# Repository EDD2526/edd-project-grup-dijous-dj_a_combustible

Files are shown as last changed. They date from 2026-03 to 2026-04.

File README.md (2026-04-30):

View this project on [CADLAB.io](https://cadlab.io/project/30195). 

# Projecte DJ_A_combustible

>**Autors: Edgar Castro i Pere Ribas
>**Versió: Final

----------

## Objectiu

Monitorització en temps real el nivell de combustible i les seves condicions (pressió/temperatura).

Control de la bomba de combustible i el tancament de seguretat de forma automàtica.

Bona connexió amb el vehicle per a que altres unitats de control tinguin accès a la informació.

## Diagrama de blocs
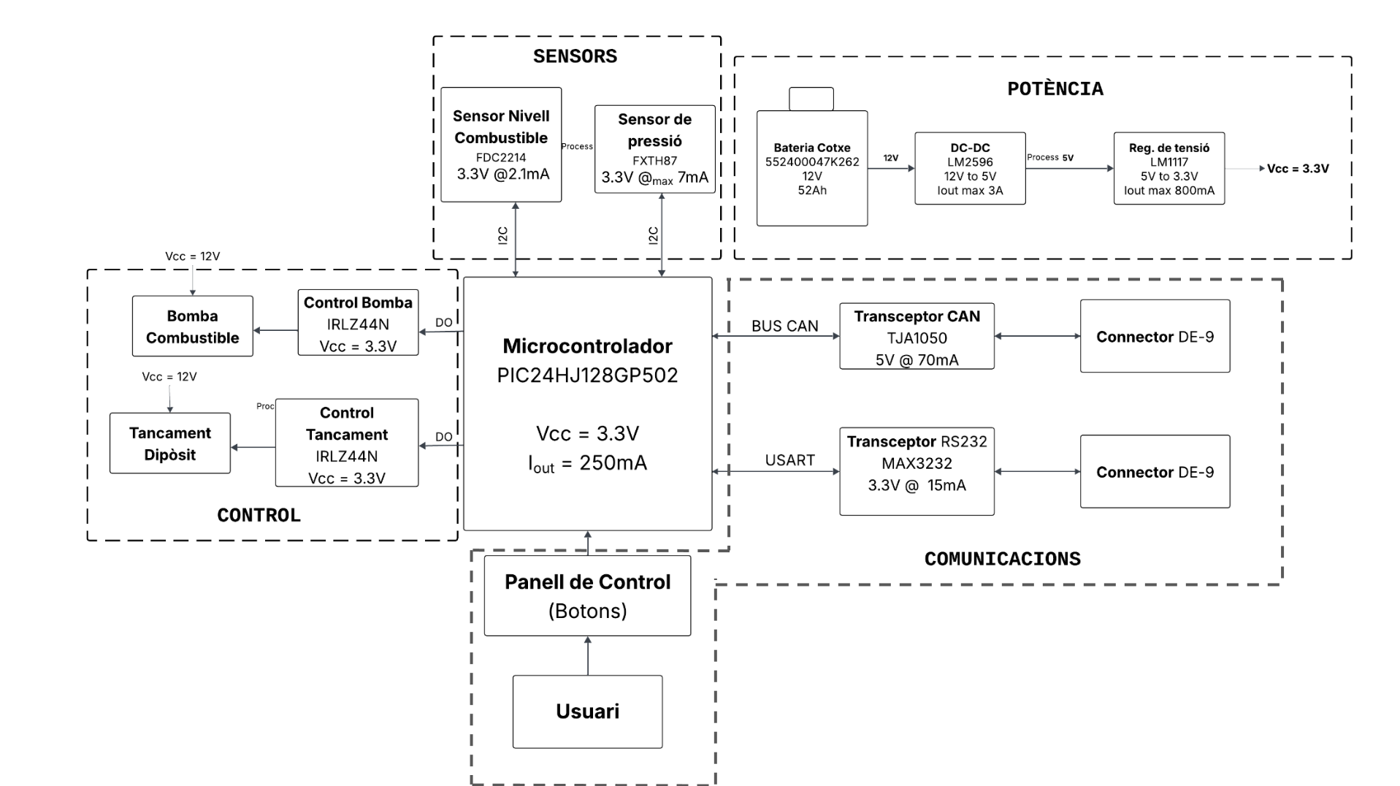
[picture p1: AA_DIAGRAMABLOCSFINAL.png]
Diagrama_de_blocs


### Descripció/funcionalitat de cada bloc

  **Etapa 1, Alimentació**
  Etapa dedicada a protegir i alimentar tots els altres blocs del projecte.
  Primer els 12V seran protegits amb díodes, i aquests serviran per a la bomba del combustible i el tancament del dipòsit.
  A partir d'aqui baixarem a 3.3V que ens servirà per alimentar el nostre Micro.

  **Etapa 2, Control**
  Etapa destinada a ser el cervell del projecte.
  Trobem el micro, encarregat de rebre informació a través dels sensors, del CAN i del MAX3232, i de donar ordres ja siguin programades o especificades per l'usuari mitjançant els botons.
  Disposem també d'un conncetor per a la possible programació, de dos DE9 pels transceptors i d'un clock.
  També tenim la botonera per a controlar el tancament del dipòsit i la bomba de combustible.

  **Etapa 3, Potència**
 Etapa destinada a controlar mitjançant dos MOSFETs els motors de la Bomba de Combustible i el Tancament del Dipòsit.
 A més per a major protecció s'han afegit dos relés i dos díodes pels sobrepics de tensió.

  **Etapa 4, Sensors**
 Etapa on hi han els sensors de nivell de combustible FDC2214 i el sensor de pressió dels pneumàtics FXTH87 amb les connexions adequades.

-----------

## Requisits / Especificacions

  * Alimentació; 12V, regulada 5V i 3.3V
  * Microcontrolador PIC24HJ128GP502
  * Mòdul RF Receptor
  * Sensor de Combustible: FDC2214
    
  ### Regles de disseny 
  * Marge mínim: 0.2mm
  * Amplada mínima de la pista: 0.1mm
  * Amplada mínima de conenxionat: 0.2mm
  * Marge de cobre a forat: 0.25mm
  * Diàmetre mínim de uVia: 0.25mm
  * Orifici mínim de uVia: 0.15mm
  * Modificacions de la serigrafia

**Classes de nodes i amplada**
  * GND → 0.2mm
  * GND_PWR → 0.5mm
  * Alimentació → 0.5mm
  * 5V → 0.3mm
  * 3.3V → 0.2mm
  * Default → 0.25mm

-----------

## Components

| Descripció | Ref | Package | Datasheet | Proveïdor | Preu Unitari | Unitats |
| --- | --- | --- | --- | --- | --- | --- |
| **Microcontrolador PIC24 (16-bit)** | U20 | SOIC-28W | [Datasheet](http://ww1.microchip.com/downloads/en/DeviceDoc/70293G.pdf) | [Mouser](https://www.mouser.es/ProductDetail/Microchip-Technology/PIC24HJ128GP502-I-SO?qs=Fllw7YelV39GXmNd3htPpg%3D%3D) | 5,86€ | 1x |
| **Mòdul RF Receptor** | XY-MK-5V | - | [Datasheet](https://www.berrybase.ch/en/product-datasheet/019234a3d36272808ea5c21625235fe6/create) | [Digikey](https://www.digikey.es) | 4,95€ | 1x |
| **Sensor Capacitiu (Combustible)** | U6 | QFN-16 | [Datasheet](https://www.ti.com/lit/ds/symlink/fdc2214.pdf) | [Mouser](https://www.mouser.es/ProductDetail/Texas-Instruments/FDC2214RGHR?qs=GJ%2F2ZGcr5uPBUC9HQa0OnA%3D%3D) | 5,38€ | 1x |
| **Relé SPST-NO (6A)** | K1, K2 | Vertical THT | [Datasheet](https://www.fujitsu.com/sg/imagesgig5/ftr-ly.pdf) | [Digikey](https://www.digikey.es) | 1,49€ | 2x |
| **MOSFET N-Channel** | Q1, Q2 | TO-220F-3 | [Datasheet](http://www.irf.com/product-info/datasheets/data/irliz44n.pdf) | [Digikey](https://www.digikey.es) | 1,29€ | 2x |
| **Regulador Step-Down 12V** | U1 | TO-263-5 | [Datasheet](http://www.ti.com/lit/ds/symlink/lm2596.pdf) | [Digikey](https://www.digikey.es) | 6,18€ | 1x |
| **Regulador LDO 3.3V** | U2 | TO-252-3 | [Datasheet](http://www.ti.com/lit/ds/symlink/lm1117.pdf) | [Digikey](https://www.digikey.es) | 1,15€ | 1x |
| **Transceptor CAN** | U3 | SOIC-8 | [Datasheet](http://www.ti.com/lit/ds/symlink/sn65hvd230.pdf) | [Digikey](https://www.digikey.es) | 1,94€ | 1x |
| **Driver RS232** | U4 | SOIC-16 | [Datasheet](https://datasheets.maximintegrated.com/en/ds/MAX3222-MAX3241.pdf) | [Digikey](https://www.digikey.es) | 1,91€ | 1x |
| **Díode Rectificador (Flyback)** | D_p_bomba1, 2 | DO-41 THT | [Datasheet](http://www.vishay.com/docs/88503/1n4001.pdf) | [Digikey](https://www.digikey.es) | 0,18€ | 2x |
| **Díode Schottky (DCDC)** | D_schottky1 | D_SMA | [Datasheet](https://ww1.microchip.com/downloads/aemdocuments/documents/HRDS/ProductDocuments/DataSheets/1n5823-25.pdf) | [Digikey](https://www.digikey.es) | 0,88€ | 1x |
| **Díode Zener 14V** | D_Zener1 | D_SOD-123 | [Datasheet](https://www.mouser.es/datasheet/3/225/1/SMBJ5338B-SMBJ5388B(SMB).pdf) | [Digikey](https://www.digikey.es) | 0,17€ | 1x |
| **Díode Protecció (MBR0520)** | D_Proteccio1 | D_SOD-123 | [Datasheet](http://www.mccsemi.com/up_pdf/MBR0520~MBR0580(SOD123).pdf) | [Digikey](https://www.digikey.es) | 0,12€ | 1x |
| **Cristall de Quars** | Y1 | SMD 5032-2 | [Datasheet](https://www.mouser.es/datasheet/3/294/1/ecx_53r.pdf) | [Digikey](https://www.digikey.es) | 0,59€ | 1x |
| **Pulsadors (Slide/DIP)** | SW1, SW2, SW3 | SMD DIP | [Datasheet](https://www.mouser.es/datasheet/3/6118/1/slw-166261-4a-ra-n-d.pdf) | [Digikey](https://www.digikey.es) | 0,95€ | 3x |
| **Connector DB9 (RS232)** | J1, J2 | DSUB-9 | [Datasheet](https://www.mouser.es/datasheet/3/59/2/CN_DSUB9SKT00.pdf) | [Mouser](https://www.mouser.es) | 23,48€ | 2x |
| **Connectors Bomba/Tancament** | J4, B1, T1 | Pin 1x02 | [Datasheet](https://www.we-online.com/components/products/datasheet/61300211121.pdf) | [Digikey](https://www.digikey.es) | 0,11€ | 3x |
| **Connector Prog. PIC (ICSP)** | J3 | Pin 1x05 | [Datasheet](https://www.we-online.com/components/products/datasheet/61300211121.pdf) | [Digikey](https://www.digikey.es) | 0,22€ | 1x |
| **Connector Prog. Sensor (BKGD)** | J5 | Pin 1x04 | [Datasheet](https://www.we-online.com/components/products/datasheet/61300211121.pdf) | [Digikey](https://www.digikey.es) | 0,16€ | 1x |
| **Inductor 33uH (DCDC)** | L_DCDC1 | SRP7028A | [Datasheet](https://www.bourns.com/docs/product-datasheets/srp7028a.pdf) | [Digikey](https://www.digikey.es) | 0,94€ | 1x |
| **Inductor 18uH (Filtre)** | L1 | L_0805 | [Datasheet](https://product.tdk.com/system/files/dam/doc/product/inductor/inductor/smd/catalog/inductor_commercial_decoupling_mlz2012_en.pdf) | [Digikey](https://www.digikey.es) | 0,11€ | 1x |
| **Ferrite Bead** | FB1 | L_1812 | [Datasheet](https://www.we-online.com/components/products/datasheet/7427922.pdf) | [Digikey](https://www.digikey.es) | 0,25€ | 1x |
| **Condensador 680uF** | Cin_DCDC1 | Radial D10mm | [Datasheet](https://industrial.panasonic.com/cdbs/www-data/pdf/RDF0000/ABA0000C1259.pdf) | [Digikey](https://www.digikey.es) | 0,93€ | 1x |
| **Condensador 220uF** | Cout_DCDC1 | Radial D10mm | [Datasheet](https://industrial.panasonic.com/cdbs/www-data/pdf/RDF0000/ABA0000C1259.pdf) | [Digikey](https://www.digikey.es) | 0,61€ | 1x |
| **Condensador 100uF** | Cout_reg1 | Radial D5mm | [Datasheet](https://industrial.panasonic.com/cdbs/www-data/pdf/RDF0000/ABA0000C1259.pdf) | [Digikey](https://www.digikey.es) | 0,33€ | 1x |
| **Condensadors 10uF** | C7, Cin_reg1 | C_0805 | [Datasheet](https://datasheets.kyocera-avx.com/AutoMLCC.pdf) | [Digikey](https://www.digikey.es) | 0,14€ | 2x |
| **Condensadors 100nF** | C1-C9, C32-33 | C_0805 | [Datasheet](https://datasheets.kyocera-avx.com/AutoMLCC.pdf) | [Digikey](https://www.digikey.es) | 0,08€ | 10x |
| **Condensadors 22p** | C10, C11 | C_0805 | [Datasheet](https://datasheets.kyocera-avx.com/AutoMLCC.pdf) | [Digikey](https://www.digikey.es) | 0,08€ | 2x |
| **Condensador 33p** | C20 | C_0805 | [Datasheet](https://datasheets.kyocera-avx.com/AutoMLCC.pdf) | [Digikey](https://www.digikey.es) | 1,04€ | 1x |
| **Resistència 10k** | R1-R21 (varies) | R_0805 | [Datasheet](https://www.vishay.com/docs/20035/dcrcwe3.pdf) | [Digikey](https://www.digikey.es) | 0,08€ | 4x |
| **Resistència 4.7k** | R3, R4 | R_0805 | [Datasheet](https://www.vishay.com/docs/20035/dcrcwe3.pdf) | [Digikey](https://www.digikey.es) | 0,08€ | 2x |
| **Resistència 220** | R22, R23 | R_0805 | [Datasheet](https://www.vishay.com/docs/20035/dcrcwe3.pdf) | [Digikey](https://www.digikey.es) | 0,16€ | 2x |
| **Resistència 120 (CAN)** | R_CAN1 | R_0805 | [Datasheet](https://www.vishay.com/docs/20035/dcrcwe3.pdf) | [Digikey](https://www.digikey.es) | 0,08€ | 1x |

-----------

## Software

### Eines:

  * KiCad 9.0 o superior
  * LTspice
  * Lucid

### Funcionalitats:

  * El tancament i obertura del tanc de combustible
  * L'activació de la bomba que subministra el combustible al motor del vehicle
  * Captar informació sobre el nivell de combustible a través d'un sensor digital per a comunicar amb l'usuari
  * Mesurar activament la pressió dels pneumàtics del cotxe. En aquest cas, amb un receptor RF es reben les dades captades per un sensor de pressió (el sensor no forma part del projecte ja que físicament no té sentit que sigui a la pcb, sinó aprop del pneumàtic).
  * Comunicar tota aquesta informació a l'usuari del vehicle i a tot el vehcile en sí a través de diferents mètodes d'enviament de dades (UART i CAN).  

-----------

## Historial de canvis
### 15/03/2026
Hem millorat el diagrama de blocs, tant l'etapa 1 com la 3.
A més he fet que les fletxes siguin més gruixudes per tal que es vegin millor.
Al KiCad he obert l'esquemàtic i he **creat els subesquemàtics**, en els quals només he posat els noms de les etapes 1 i 3.
I he fet una **carpeta** per anar posant les millores dels **diagràmes de **blocs**.
Realment del diagrama de blocs només quedaria posar el **nom i especificacions generals dels components que falten**,  acabar de modificar una mical del **disseny del diagrama** i ja estaria acabat.

### 19/03/2026
Hem millorat el diagrama de blocs, amb les correccions dels professors.
També hem començat la part esquemàtica de les diferents etapes a KiCad. En general, s'ha avançat gran part, quedarien connectar pocs pins i definir-los correctament, entendre bé el funcionament i les correccions del professor. 
A més, també haurem de millorar l'organització dels subesquemàtics creats a la carpeta compartida per tal d'aquesta manera tenir una millor visualització i entendre les etapes millor. 
Properament haurem de assignar valors als diferents components i optimitzar algun circuit

### 22/03/2026
S'ha *finalitzat definitivament el diagram de blocs*.
A l'etapa de control s'ha **afegit** un **relé** per a major **protecció** per al microcontrolador degut a les grans càrregues i potències que pot comportar el funcionament de la bomba i el tancament.
S'ha **afegit** el símbol del sensor de combustible **FDC2214**, falta **crear** el símbol del sensor de pressió **FXTH87**

### 24/03/2026
A dia d'avui, en principi no queda pràcticament res (de la part de l'esquemàtic). S'ha avançat gran part del que ens vam proposar en la darrera sessió de pràctiques, com la forma dels pins, afegir els pins que faltaven, els valors dels components, etc., juntament amb les correccions del professor. A banda d'això, també s'ha afegit una part de programació ICSP per a que l'usuari pugui controlar al seu gust mitjançant un connector extern del propi usuari al microcontrolador. 
A la tarda d'avui, només queda (de moment) crear el símbol del sensor de pressió i connectar els pins corresponents.

### 25/03/2026
**Esquemàtic acabat** abans de l'última sessió (a falta de les correccions que es faràn demà a classe).
S'ha continuat fent el Readme on s'han anat emplenant diferents apartats.
A banda d'això s'hauria d'**anar triant les petjades**, sobretot pels símbols que hem creat nosaltres o els que no estem acostumats a treballar, ja que per components passius o que ja hem tocat, les petjades suposem que seran les mateixes i que no les haurem de crear ni afegir al KiCad

### 29/03/2026
La **majoria de petjades s'han afegit**. Tots els components que no son resistències o capacitats ja tenen **petjada**.
Falta **mirar** els **pins FXTH87** ja que els pins possiblement estiguin **mal posats** i el **footprint no coincideixi** i falta repassar el propi datasheet per saber quin footprint triar.
*Altres footprints que falten:*
Cristall
Connectors 1x2 i 1x5
Díodes
Bobines
Resistències i Capacitats
També s'hauràn d'afegir les petjades i datasheets al README

### 04/04/2026
**Totes les petjades afegides**
Sensor de pressió acabat
Falta posar les petjades al readme
**Esquemàtic acabat (en teoria)**

### 08/04/2026
**Placement V1**, falta posar tots els components passius, però com és un placement i a sobre quasi al 100% s'haurà de canviar una mica, posar aquests components és perdre el temps.
Hem començat també a posar els proveïdors i els preus a la llista del Readme i s'ha actualitzat la foto per a que es vegi

### 15/04/2026
Començament del ruteig

### 16/04/2026
Modificació correccions per part del professorat. Afegim captures de diferents versions de del routing (ERC amb 0 errors). Faltaria veure si hi ha alguna cosa a corregir i passar a la part final del projecte.

### 29/04/2026
Últims retocs al esquemàtic i al layout. S'ha fet la presentació, final, s'han afegit els gerbers, BOM, fotos 3D del layout final i fotos de l'esquemàtic.
Pressupost fet i afegida la carpeta del pressupost al projecte.
**Falta acabar el readme, la taula de components**

### 30/04/2026
Tot preparat (des d'ahir). Presentació realitzada amb el procés d'aquest projecte. Nervis d'últim dia, però està controlat!

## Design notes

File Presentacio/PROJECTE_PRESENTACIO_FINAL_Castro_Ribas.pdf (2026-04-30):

# Projecte Combustible

## Edgar Castro i Pere Ribas

PRESENTACIÓ FINAL
30/04/2026

## Objectius

→ Monitorització en temps real el nivell de combustible i les seves condicions (pressió/temperatura).

→ Control de la bomba de combustible i el tancament de seguretat de forma automàtica.

→ Bona connexió amb el vehicle per a que altres unitats de control tinguin accès a la informació.

## Requeriments i especificacions

- Alimentació; 12V, regulada 5V i 3.3V
- Microcontrolador PIC24HJ128GP502
- Mòdul RF Receptor
- Sensor de Combustible: FDC2214

## Requeriments i especificacions

- Regles de disseny

→ Marge mínim: 0.2mm

→ Amplada mínima de la pista: 0.1mm

→ Amplada mínima de conenxionat: 0.2mm

→ Marge de cobre a forat: 0.25mm

→ Diàmetre mínim de uVia: 0.25mm

→ Orifici mínim de uVia: 0.15mm

→ Modificacions de la serigrafia

## Requeriments i especificacions

- Classes de nodes i amplada

GND → 0.2mm

GND_PWR → 0.5mm

Alimentació → 0.5mm

5V → 0.3mm

3.3V → 0.2mm

Default → 0.25mm

## Diagrama de blocs final

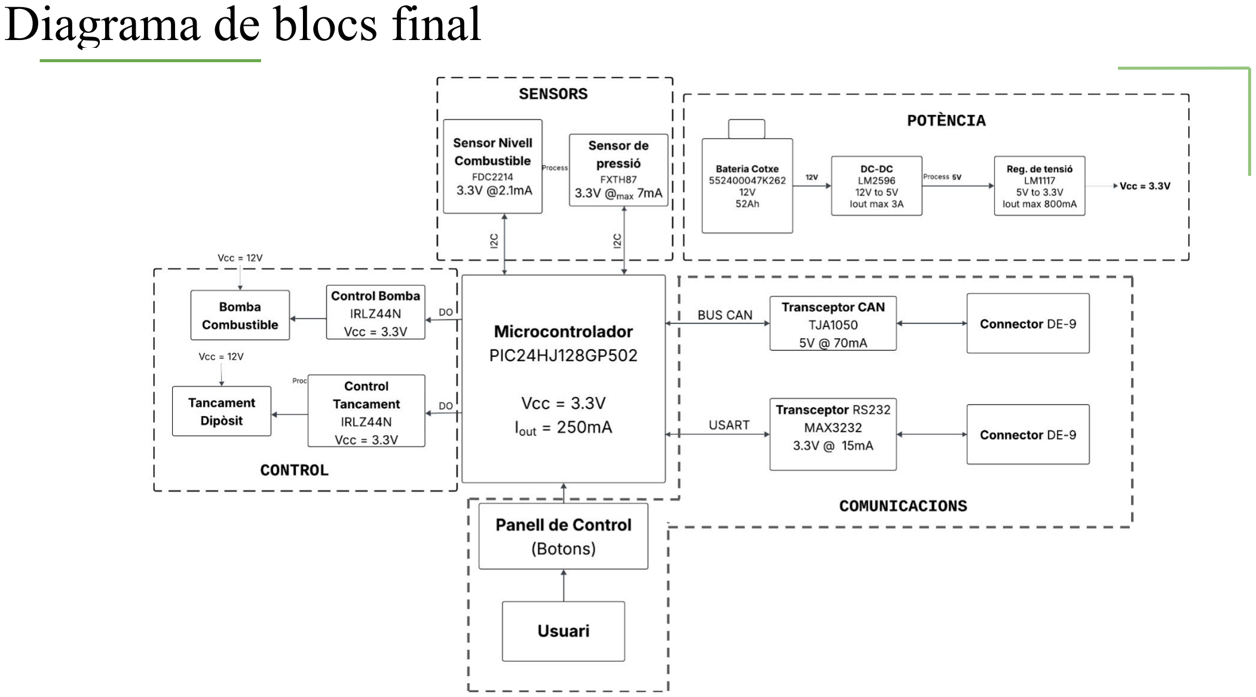
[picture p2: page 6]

## Diferents funcionalitats de cada bloc

Bloc 1 → Alimentació

- Protecció i alimentació de la resta de blocs. Començant en 12 [V] i passant a 3V3.

Bloc 2 → Control

- Cervell del projecte. Encarregat de rebre i donar ordres (programades o per part de l’usuari) mitjançant els seus connectors DE9.

## Diferents funcionalitats de cada bloc

Bloc 3 → Potència

- S’encarrega, mitjançant MOSFETs del control de la bomba del combustible i del control del tancament, amb dos relés i dos díodes per una major protecció.

Bloc 4 → Sensors

- Una última etapa amb funció de sensors, per controlar la pressió dels pneumàtics i el nivell de combustible.

## Diferents decisions que hem hagut de prendre

Creació de símbols i alternatives (gràcies a datasheets).

Col·locació dels components a l’hora de realitzar el layout.

Sensor de pressió o receptor RF

## Esquemàtic

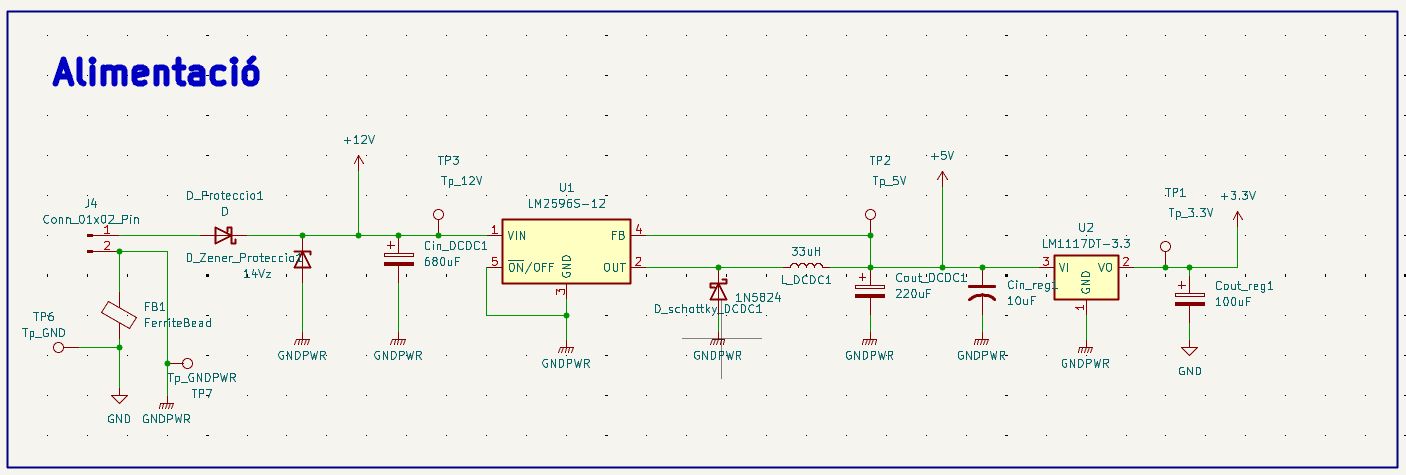
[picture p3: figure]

## Esquemàtic

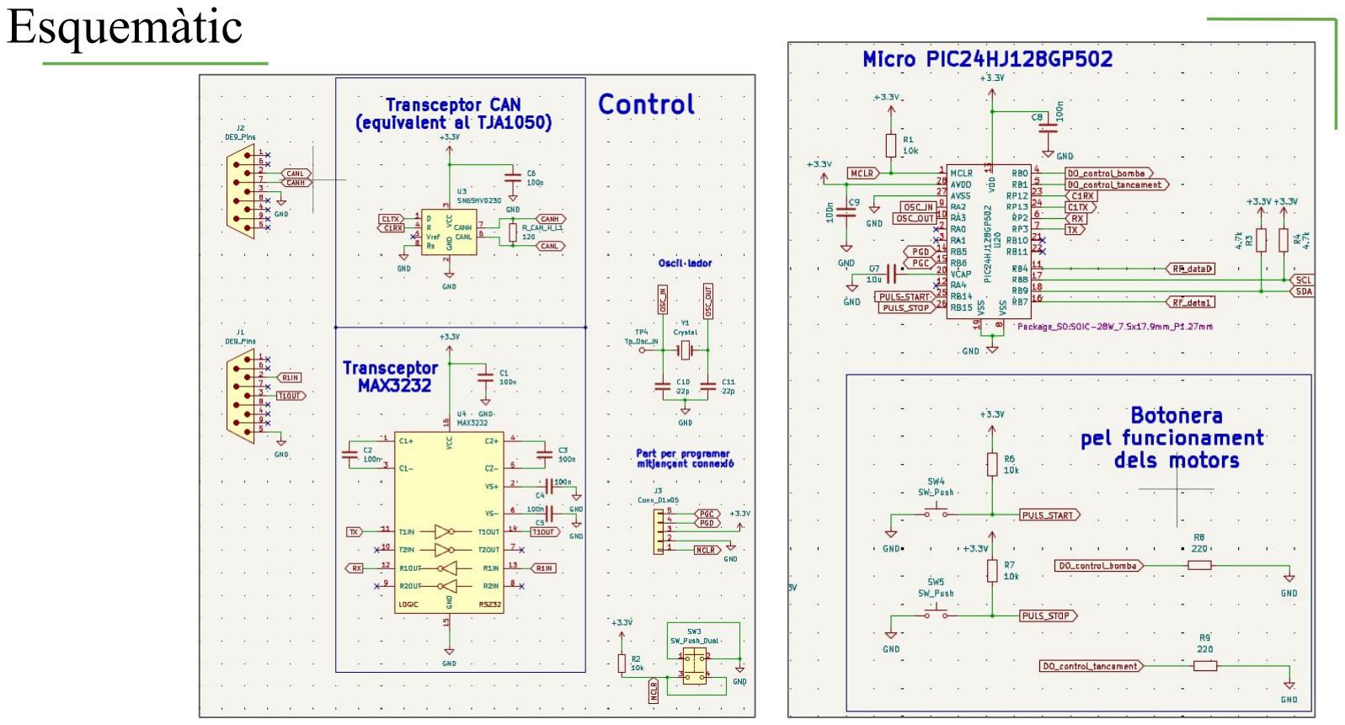
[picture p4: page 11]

## Esquemàtic

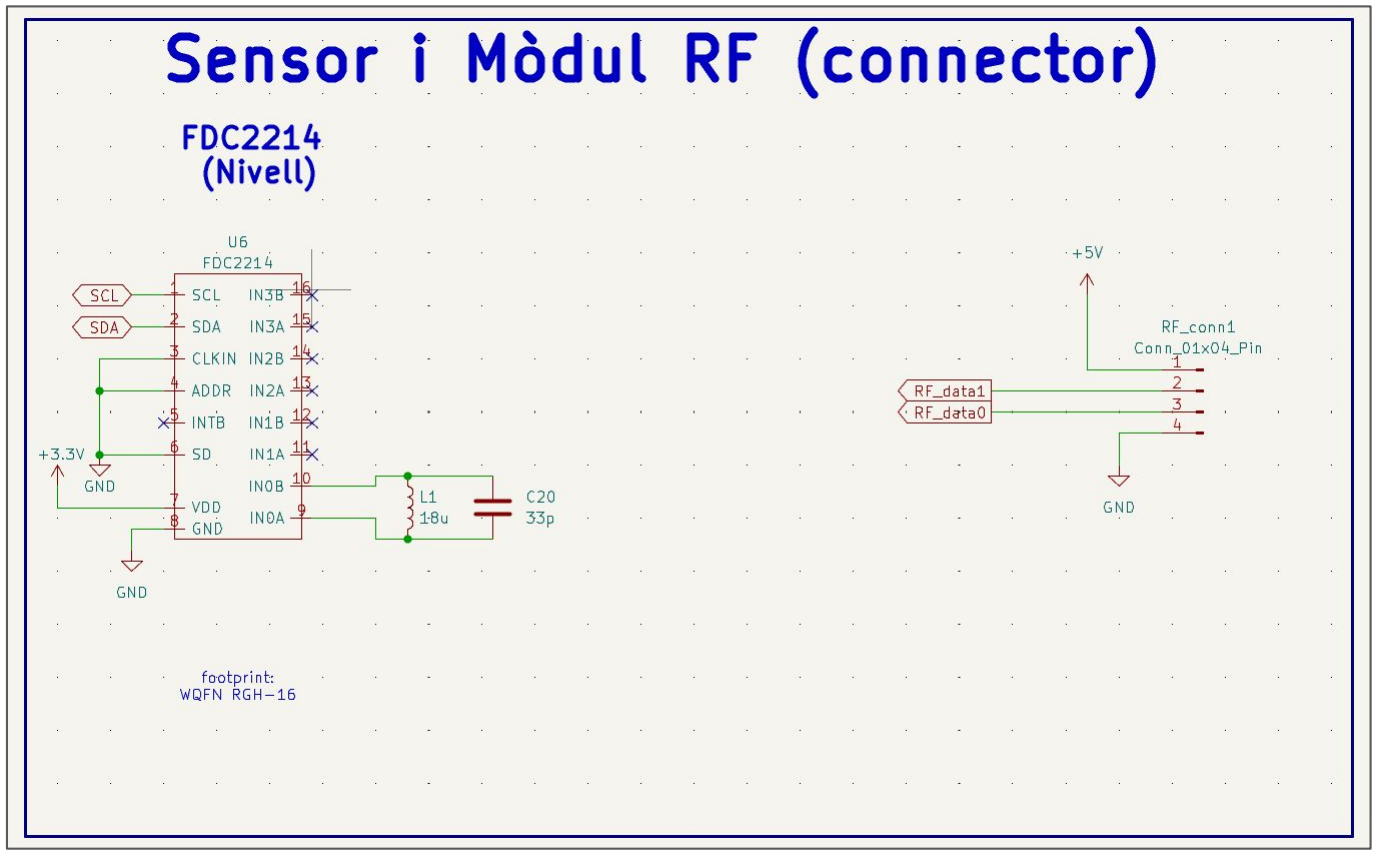
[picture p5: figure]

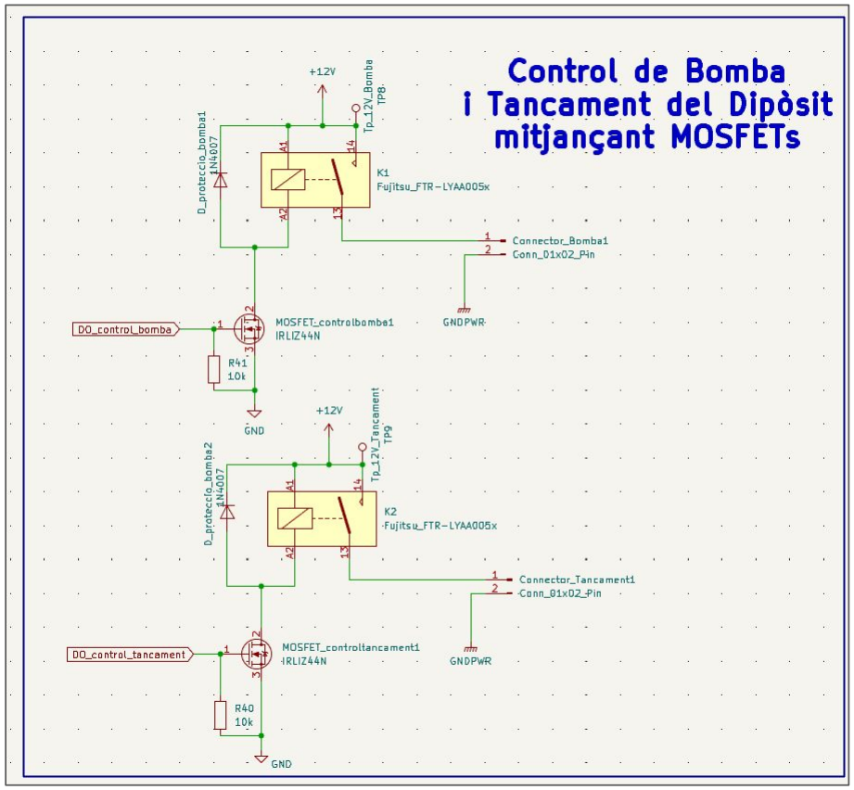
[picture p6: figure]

## Esquemàtic

## Layout

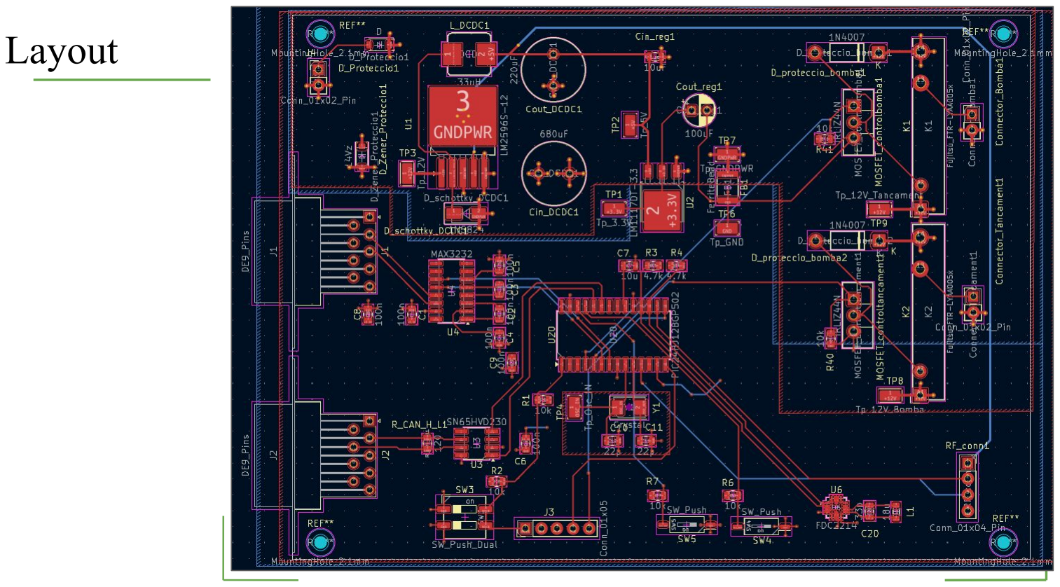
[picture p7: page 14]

## Layout 3D

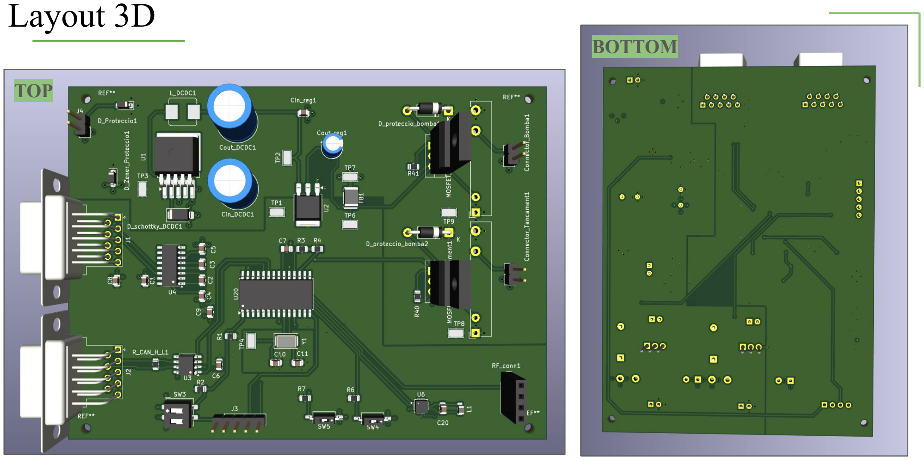
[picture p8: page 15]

TOP

BOTTOM

## Anàlisi de costos

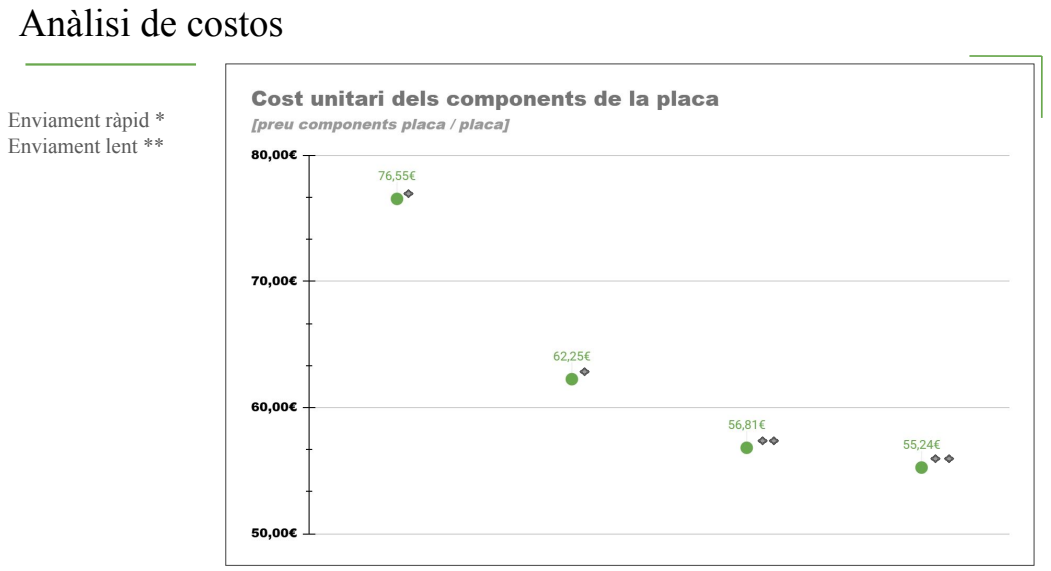
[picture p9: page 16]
Enviament ràpid * Enviament lent **

## Anàlisi de costos

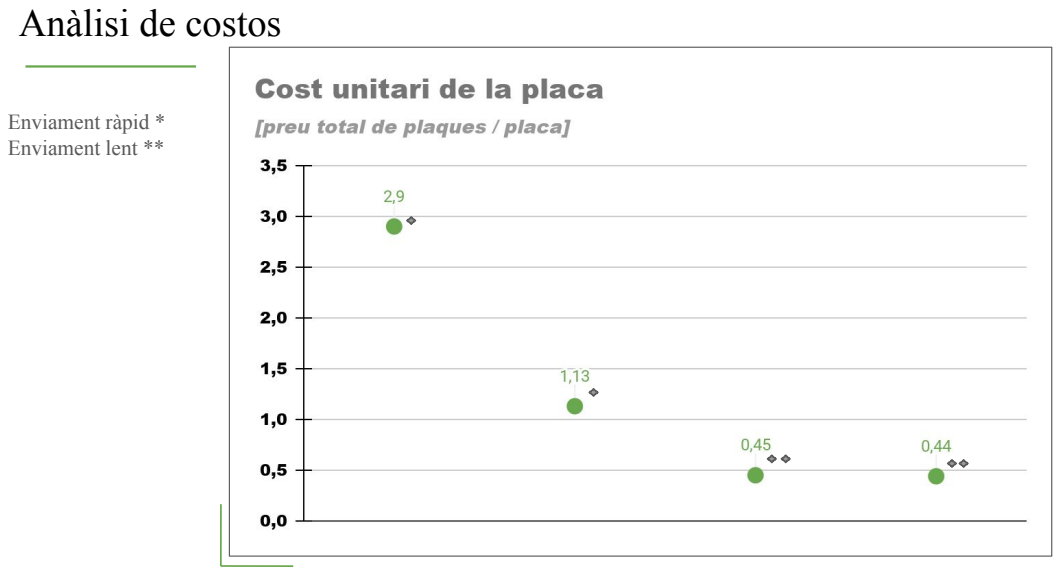
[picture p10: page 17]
Enviament ràpid * Enviament lent **

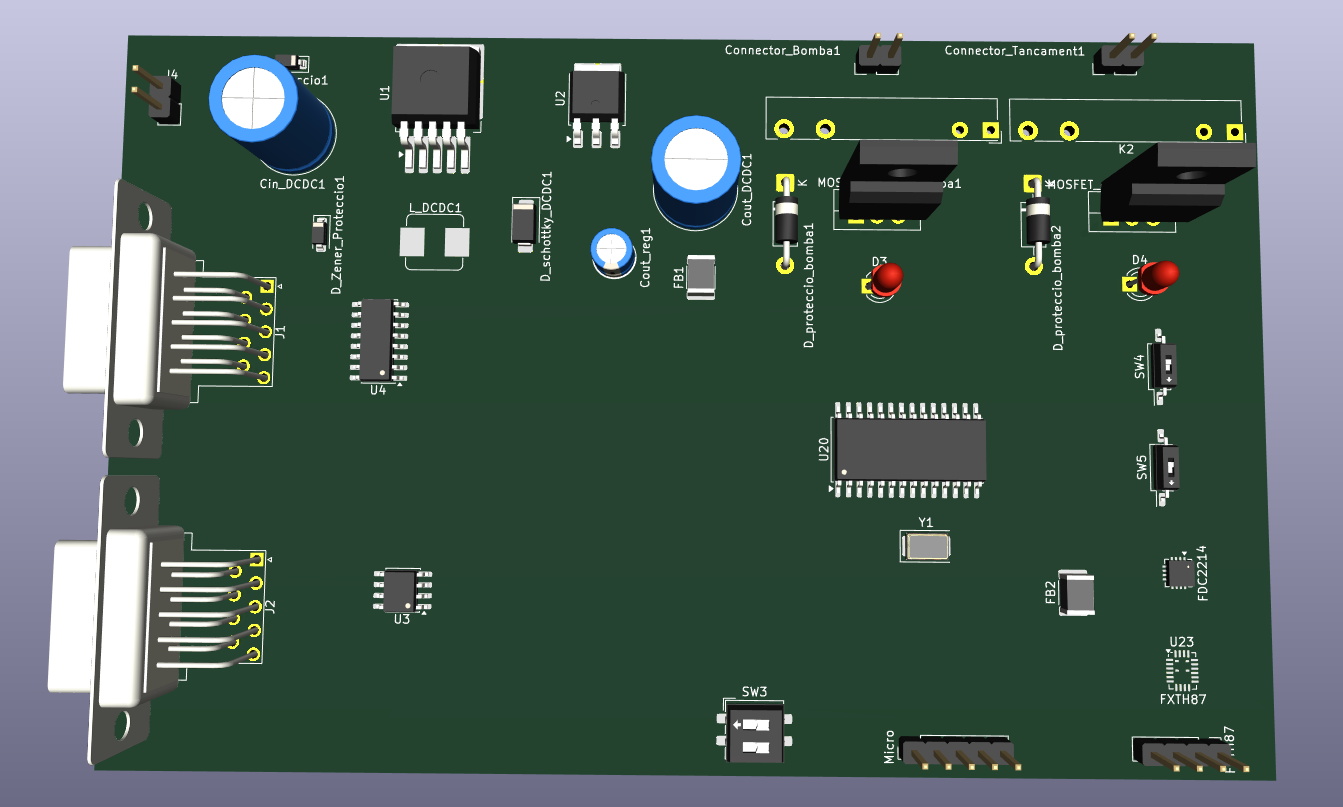
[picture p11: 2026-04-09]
Layout/layout3D_v1.png

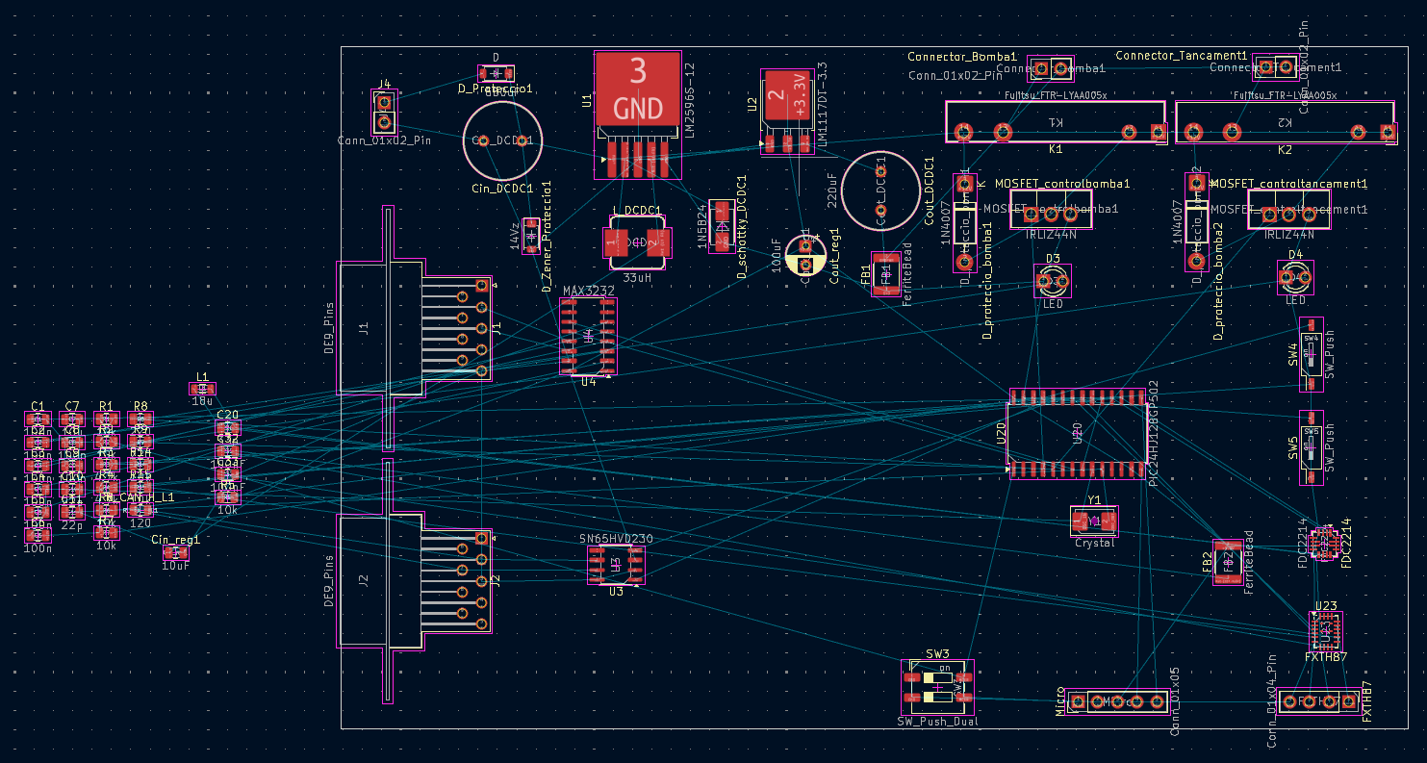
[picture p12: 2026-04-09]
Layout/layout_v1.png

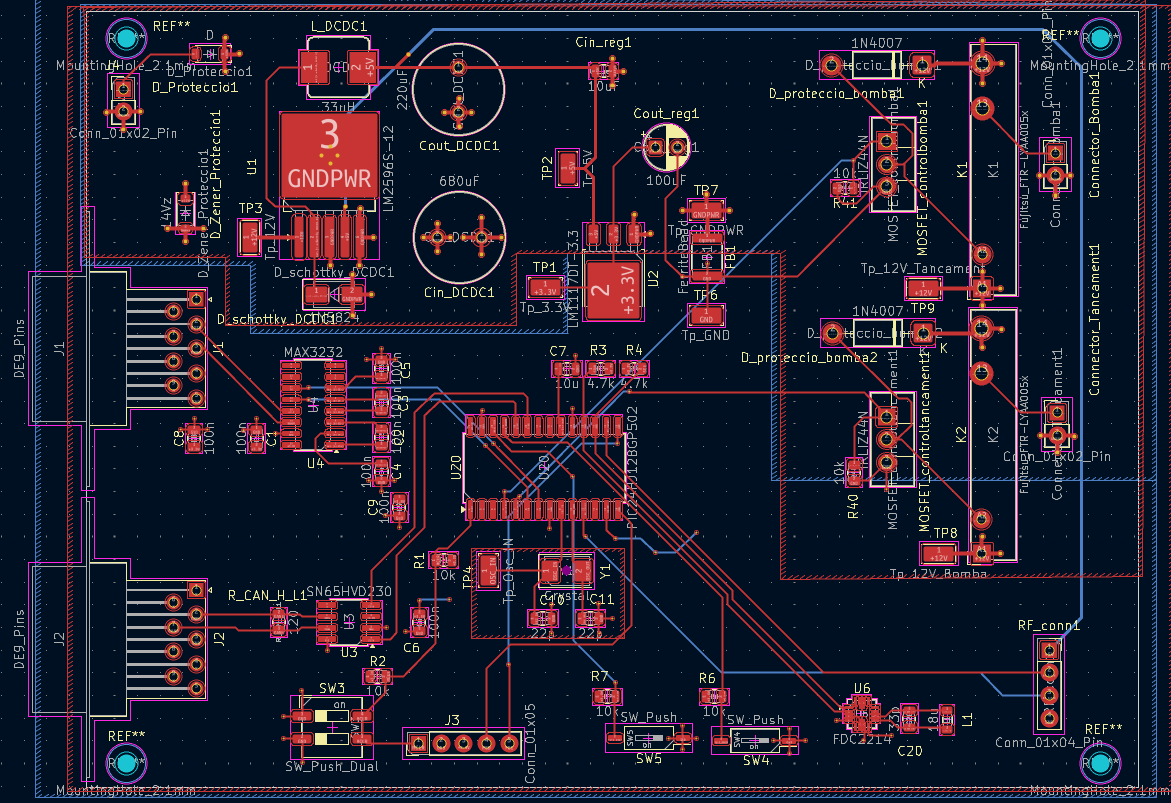
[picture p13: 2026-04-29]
Layout/AA_layoutfinal.png

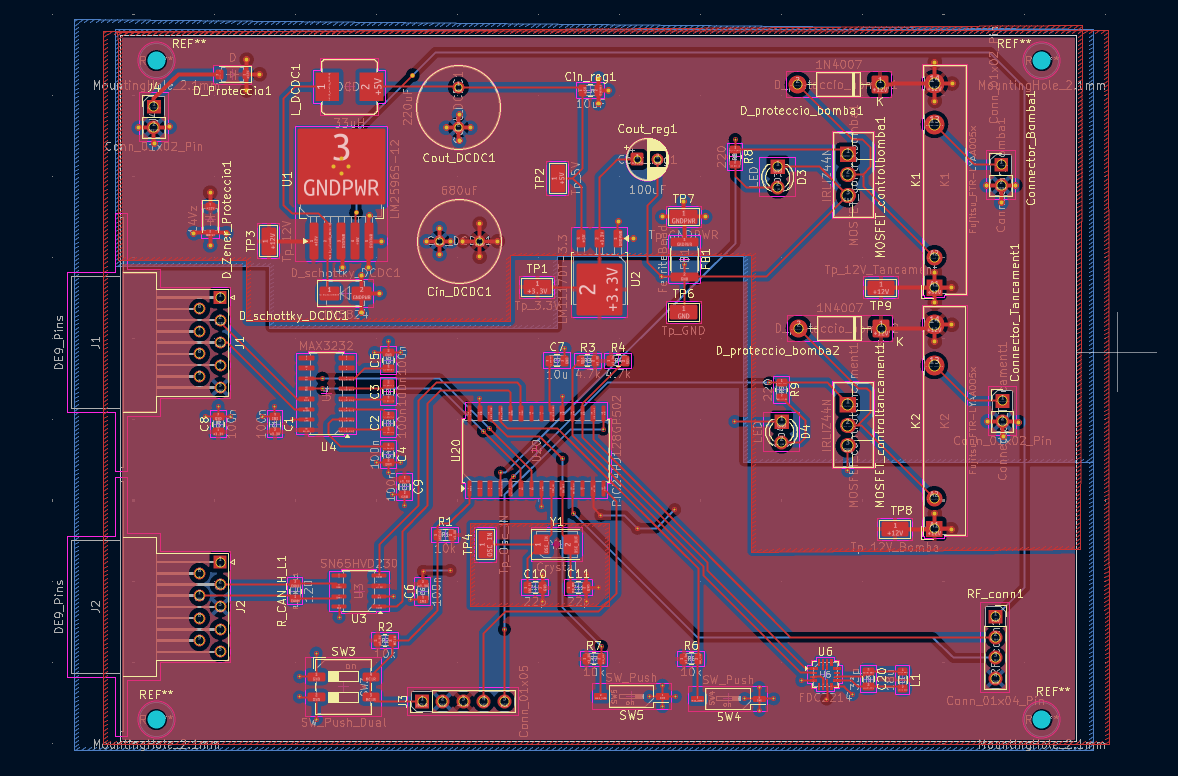
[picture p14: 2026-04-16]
Layout/layout_v2.png

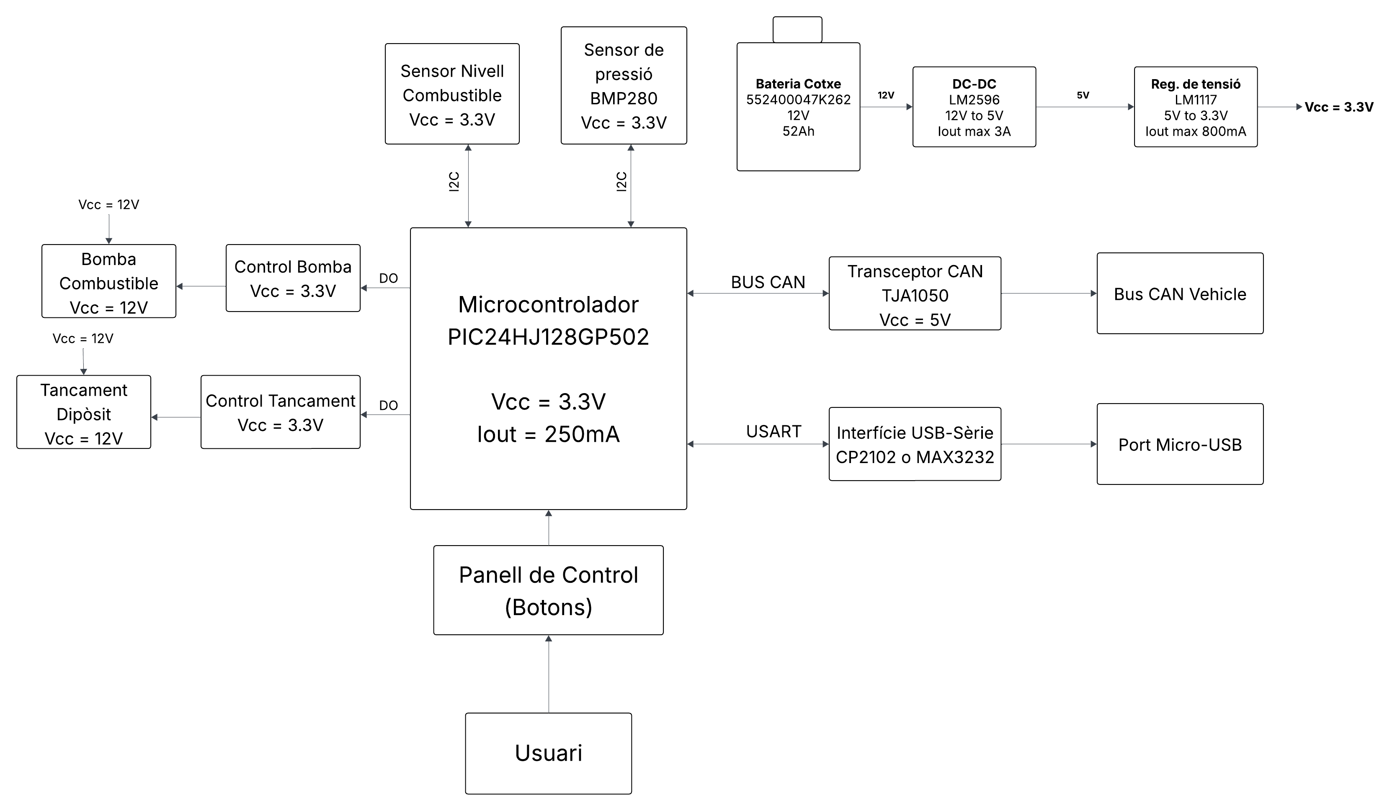
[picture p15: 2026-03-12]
DIAGRAMA BLOCS/DiagramaBlocsDIA1.png

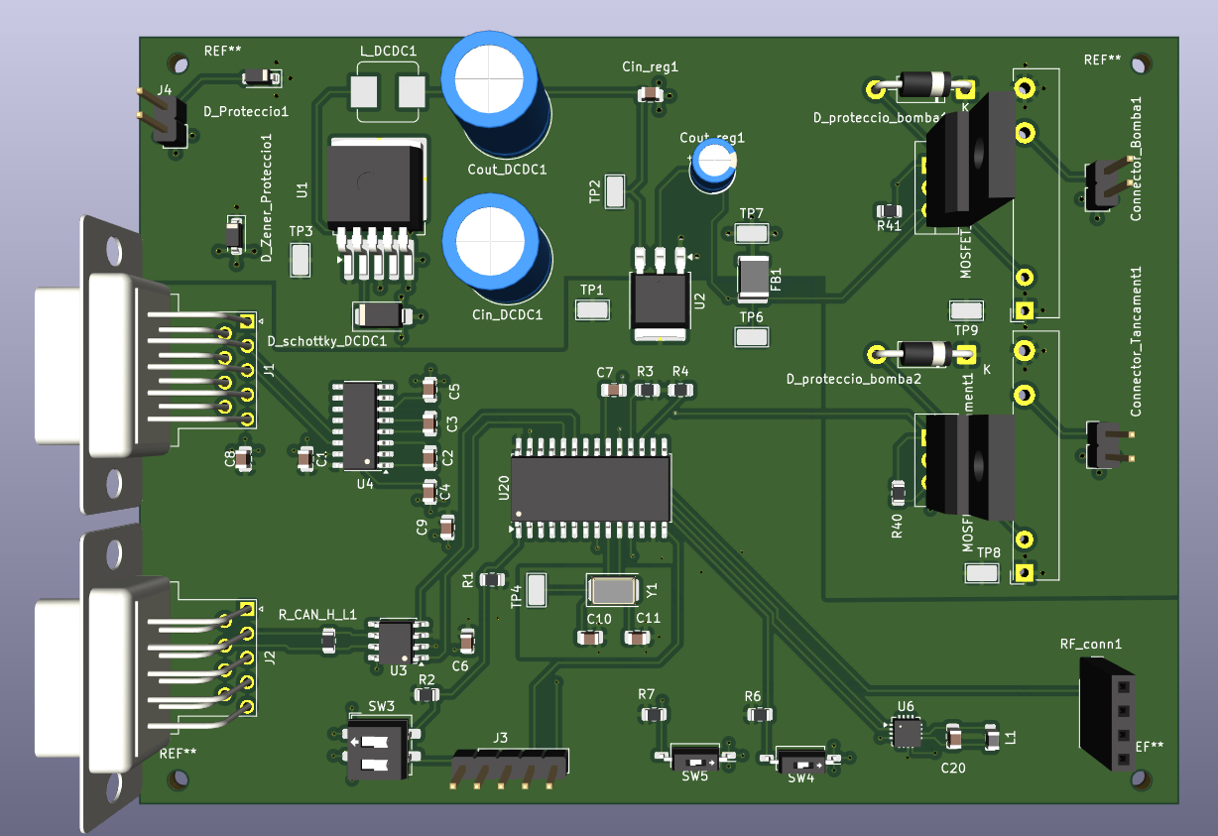
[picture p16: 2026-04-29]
Layout/AA_layout3D_top.png

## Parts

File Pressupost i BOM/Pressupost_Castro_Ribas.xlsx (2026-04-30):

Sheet: BOM
Descripció | Ref | Package | Datasheet | Proveïdor | Preu Unitari | Unitats | Preu x10* | Preu x50* | Preu x1.000** | Preu x20.000** |  | Enviament ràpid* | Enviament lent**
Microcontrolador PIC24 (16-bit) | U20 | SOIC-28W | Datasheet (http://ww1.microchip.com/downloads/en/DeviceDoc/70293G.pdf) | Mouser (https://www.mouser.es/ProductDetail/Microchip-Technology/PIC24HJ128GP502-I-SO?qs=Fllw7YelV39GXmNd3htPpg%3D%3D) | 5.86€ | 1x | 55.67€ | 268.00€ | 4870.00€ | 97400.00€
Mòdul RF Receptor | XY-MK-5V | - | Datasheet (https://mm.digikey.com/Volume0/opasdata/d220001/medias/docus/2092/QAM-RX10.pdf) | Digikey (https://www.digikey.es/es/products/detail/rf-solutions/QAM-RX10-433/6235156) | 4.95€ | 1x | 42.93€ | 203.06€ | 3291.15€ | 65823.00€
Sensor Capacitiu (Combustible) | U6 | QFN-16 | Datasheet (https://www.ti.com/lit/ds/symlink/fdc2214.pdf) | Mouser (https://www.mouser.es/ProductDetail/Texas-Instruments/FDC2214RGHR?qs=GJ%2F2ZGcr5uPBUC9HQa0OnA%3D%3D) | 5.38€ | 1x | 51.60€ | 236.00€ | 4150.00€ | 76800.00€
Relé SPST-NO (6A) | K1, K2 | Vertical THT | Datasheet (https://www.fujitsu.com/sg/imagesgig5/ftr-ly.pdf) | Digikey (https://www.digikey.es/es/products/detail/omron-electronics-inc-emc-div/G5LE-14-DC12/280369) | 1.49€ | 2x | 26.14€ | 116.46€ | 2074.34€ | 38251.60€
MOSFET N-Channel | Q1, Q2 | TO-220F-3 | Datasheet (http://www.irf.com/product-info/datasheets/data/irliz44n.pdf) | Digikey (https://www.digikey.es/es/products/detail/diodes-incorporated/DMT6009LCT/6051857) | 1.29€ | 2x | 25.80€ | 54.19€ | 708.10€ | 11925.20€
Regulador Step-Down 12V | U1 | TO-263-5 | Datasheet (http://www.ti.com/lit/ds/symlink/lm2596.pdf) | Digikey (https://www.digikey.es/es/products/detail/texas-instruments/LM2596S-12-NOPB/363703) | 6.18€ | 1x | 47.63€ | 208.64€ | 3664.91€ | 71617.00€
Regulador LDO 3.3V | U2 | TO-252-3 | Datasheet (http://www.ti.com/lit/ds/symlink/lm1117.pdf) | Digikey (https://www.digikey.es/es/products/detail/texas-instruments/LM1117DTX-3-3-NOPB/366727) | 1.15€ | 1x | 8.40€ | 37.58€ | 590.36€ | 10627.60€
Transceptor CAN | U3 | SOIC-8 | Datasheet (http://www.ti.com/lit/ds/symlink/sn65hvd230.pdf) | Digikey (https://www.digikey.es/es/products/detail/texas-instruments/SN65HVD230DR/404367) | 1.94€ | 1x | 13.96€ | 63.70€ | 1040.28€ | 18885.00€
Driver RS232 | U4 | SOIC-16 | Datasheet (https://datasheets.maximintegrated.com/en/ds/MAX3222-MAX3241.pdf) | Digikey (https://www.digikey.es/es/products/detail/texas-instruments/MAX3222CPWR/484771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) | 1.91€ | 1x | 13.96€ | 63.70€ | 1040.28€ | 18885.00€
Díode Rectificador (Flyback) | D_p_bomba1, 2 | DO-41 THT | Datasheet (http://www.vishay.com/docs/88503/1n4001.pdf) | Digikey (https://www.digikey.es/es/products/detail/mcc-micro-commercial-components/1N4007-TP/773644) | 0.18€ | 2x | 2.18€ | 6.71€ | 75.94€ | 904.00€
Díode Schottky (DCDC) | D_schottky1 | D_SMA | Datasheet (https://ww1.microchip.com/downloads/aemdocuments/documents/HRDS/ProductDocuments/DataSheets/1n5823-25.pdf) | Digikey (https://www.digikey.es/es/products/detail/onsemi/MBRS340T3G/918645?s=N4IgTCBcDaILICEBKBlAzAFgAwBU0HEQBdAXyA) | 0.88€ | 1x | 5.46€ | 26.95€ | 246.60€ | 3661.40€
Díode Zener 14V | D_Zener1 | D_SOD-123 | Datasheet (https://www.mouser.es/datasheet/3/225/1/SMBJ5338B-SMBJ5388B(SMB).pdf) | Digikey (https://www.digikey.es/es/products/detail/diodes-incorporated/BZT52C15-7-F/755469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) | 0.17€ | 1x | 1.03€ | 5.10€ | 40.80€ | 542.64€
Díode Protecció (MBR0520) | D_Proteccio1 | D_SOD-123 | Datasheet (http://www.mccsemi.com/up_pdf/MBR0520~MBR0580(SOD123).pdf) | Digikey (https://www.digikey.es/es/products/detail/smc-diode-solutions/1N4148W/6022450) | 0.12€ | 1x | 0.71€ | 3.55€ | 27.79€ | 362.32€
Cristall de Quars | Y1 | SMD 5032-2 | Datasheet (https://www.mouser.es/datasheet/3/294/1/ecx_53r.pdf) | Digikey (https://www.digikey.es/es/products/detail/abracon-llc/ABM3B-8-000MHZ-B2-T/1873166) | 0.59€ | 1x | 5.15€ | 23.34€ | 383.99€ | 6675.20€
Pulsadors (Slide/DIP) | SW1, SW2, SW3 | SMD DIP | Datasheet (https://www.mouser.es/datasheet/3/6118/1/slw-166261-4a-ra-n-d.pdf) | Digikey (https://www.digikey.es/es/products/detail/nidec-components/CHS-01TA/948314) | 0.95€ | 3x | 22.21€ | 98.99€ | 1512.96€ | 28837.20€
Connector DB9 (RS232) | J1, J2 | DSUB-9 | Datahseet (https://www.mouser.es/datasheet/3/59/2/CN_DSUB9SKT00.pdf) | Mouser (https://www.mouser.es/ProductDetail/ITT-Cannon/DE-9S-1A8N-A197?qs=5aG0NVq1C4whoEtJUIiFjA%3D%3D) | 23.48€ | 2x | 399.20€ | 1529.00€ | 30580.00€ | 611600.00€
Connectors Bomba/Tancament | J4, B1, T1 | Pin 1x02 | Datasheet (https://www.we-online.com/components/products/datasheet/61300211121.pdf) | Digikey (https://www.digikey.es/es/products/detail/w%C3%BCrth-elektronik/61300211121/4846823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) | 0.11€ | 3x | 2.30€ | 8.70€ | 159.09€ | 3181.80€
Connector Prog. PIC (ICSP) | J3 | Pin 1x05 | Datasheet (https://www.we-online.com/components/products/datasheet/61300211121.pdf) | Digikey (https://www.digikey.es/es/products/detail/w%C3%BCrth-elektronik/61300511121/4846831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) | 0.22€ | 1x | 1.91€ | 6.67€ | 116.05€ | 2292.20€
Connector Prog. Sensor (BKGD) | J5 | Pin 1x04 | Datasheet (https://www.we-online.com/components/products/datasheet/61300211121.pdf) | Digikey (https://www.digikey.es/es/products/detail/w%C3%BCrth-elektronik/61300411121/4846827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) | 0.16€ | 1x | 1.40€ | 4.86€ | 84.86€ | 1676.00€
Inductor 33uH (DCDC) | L_DCDC1 | SRP7028A | Datasheet (https://www.bourns.com/docs/product-datasheets/srp7028a.pdf) | Digikey (https://www.digikey.es/es/products/detail/bourns-inc/SRP7028A-330M/6153697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) | 0.94€ | 1x | 7.69€ | 33.55€ | 520.26€ | 8459.60€
Inductor 18uH (Filtre) | L1 | L_0805 | Datasheet (https://product.tdk.com/system/files/dam/doc/product/inductor/inductor/smd/catalog/inductor_commercial_decoupling_mlz2012_en.pdf) | Digikey (https://www.digikey.es/es/products/detail/tdk/MLF2012C180KT000/504231) | 0.11€ | 1x | 0.88€ | 4.40€ | 59.79€ | 909.60€
Ferrite Bead | FB1 | L_1812 | Datasheet (https://www.we-online.com/components/products/datasheet/742792514.pdf) | Digikey (https://www.digikey.es/es/products/detail/w%C3%BCrth-elektronik/742792514/1639047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) | 0.25€ | 1x | 2.41€ | 11.13€ | 185.21€ | 3704.20€
Condensador 680uF | Cin_DCDC1 | Radial D10mm | Datasheet (https://industrial.panasonic.com/cdbs/www-data/pdf/RDF0000/ABA0000C1259.pdf) | Digikey (https://www.digikey.es/es/products/detail/panasonic-industry/EEU-FR1E681/2433556) | 0.93€ | 1x | 5.93€ | 22.56€ | 304.45€ | 5185.60€
Condensador 220uF | Cout_DCDC1 | Radial D10mm | Datasheet (https://industrial.panasonic.com/cdbs/www-data/pdf/RDF0000/ABA0000C1259.pdf) | Digikey (https://www.digikey.es/es/products/detail/panasonic-industry/EEU-FR1E221/9921023) | 0.61€ | 1x | 3.83€ | 14.35€ | 187.07€ | 3130.20€
Condensador 100uF | Cout_reg1 | Radial D5mm | Datasheet (https://industrial.panasonic.com/cdbs/www-data/pdf/RDF0000/ABA0000C1259.pdf) | Digikey (https://www.digikey.es/es/products/detail/panasonic-industry/EEU-FR1C101/2433525) | 0.33€ | 1x | 2.04€ | 7.48€ | 92.82€ | 1511.40€
Condensadors 10uF | C7, Cin_reg1 | C_0805 | Datasheet (https://datasheets.kyocera-avx.com/AutoMLCC.pdf) | Digikey (https://www.digikey.es/es/products/detail/samsung-electro-mechanics/CL21A106KAYNNNG/3894413) | 0.14€ | 2x | 1.52€ | 4.64€ | 62.60€ | 855.76€
Condensadors 100nF | C1-C9, C32-33 | C_0805 | Datasheet (https://datasheets.kyocera-avx.com/AutoMLCC.pdf) | Digikey (https://www.digikey.es/es/products/detail/samsung-electro-mechanics/CL21B104KBCNNNC/3886661) | 0.08€ | 10x | 1.85€ | 6.63€ | 90.16€ | 1372.00€
Condensadors 22p | C10, C11 | C_0805 | Datasheet (https://datasheets.kyocera-avx.com/AutoMLCC.pdf) | Digikey (https://www.digikey.es/es/products/detail/samsung-electro-mechanics/CL21C220JBANNNC/3886705) | 0.08€ | 3x | 1.02€ | 2.93€ | 2.93€ | 436.80€
Condensador 33p | C20 | C_0805 | Datasheet (https://calchip.com/wp-content/uploads/2026/01/CHV-Series.pdf) | Digikey (https://www.digikey.es/es/products/detail/cal-chip-electronics-inc/CHV1812N3K0330JCT/22238703) | 1.04€ | 1x | 6.77€ | 26.64€ | 390.49€ | 6783.20€
Resistència 10k | R1-R21 (varies) | R_0805 | Datasheet (https://www.vishay.com/docs/20035/dcrcwe3.pdf) | Digikey (https://www.digikey.es/es/products/detail/stackpole-electronics-inc/RMCF0805FT10K0/1760676) | 0.08€ | 6x | 0.79€ | 2.52€ | 177.00€ | 354.00€
Resistència 4.7k | R3, R4 | R_0805 | Datasheet (https://www.vishay.com/docs/20035/dcrcwe3.pdf) | Digikey (https://www.digikey.es/es/products/detail/panasonic-industry/ERA-6AEB472V/1465765) | 0.08€ | 2x | 1.18€ | 4.94€ | 41.08€ | 1300.80€ |  |  |  |  |  | Aquest gràfic es veu fatal degut a que la difernecia passa de 10 plaques a 20.000 fa que no quedi bé
Resistència 220 | R22, R23 | R_0805 | Datasheet (https://www.vishay.com/docs/20035/dcrcwe3.pdf) | Digikey (https://www.digikey.es/es/products/detail/rohm-semiconductor/ESR10EZPF2200/1983511) | 0.16€ | 2x | 1.64€ | 4.67€ | 31.00€ | 813.20€
Resistència 120 (CAN) | R_CAN1 | R_0805 | Datasheet (https://www.vishay.com/docs/20035/dcrcwe3.pdf) | Digikey (https://www.digikey.es/es/products/detail/te-connectivity-passive-product/CRGCQ0805F120R/8576340) | 0.08€ | 1x | 0.33€ | 1.03€ | 9.87€ | 125.80€
PREU TOTAL |  |  |  |  |  |  | 765.52€ | 3112.67€ | 56812.23€ | 1104889.32€
PREU TOTAL UNITARI [ preu dels components de la placa / placa ] |  |  |  |  |  |  | 76.55€ | 62.25€ | 56.81€ | 55.24€
 |  |  |  |  |  |  |  |  |  |  | Unitats | 10 | 50 | 1000 | 20000
 |  |  |  |  |  |  |  |  |  |  | Preu unitari | 76 | 62 | 56 | 55

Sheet: PCB
Unitats | x10* | x50* | x1.000** | x20.000** | Enviament ràpid* | Enviament lent**
Preu | 28.99€ | 56.27€ | 450.95€ | 8826.04€ |  |  | PCB ESPECIFICACIONS (https://jlcpcb.com/)
Especificacions de muntatge | Stencils top i bottom Enviament 2-3 dies | Stencils top i bottom Enviament 2-3 dies | No stencils Panel by jlcpcb PCBA top i bottom | No stencils Panel by jlcpcb PCBA top i bottom
Preu/ut. | 2.90€/unitat | 1.13€/unitat | 0.45€/unitat | 0,44€/unitat
 | 2.9 | 1.13 | 0.45 | 0.44

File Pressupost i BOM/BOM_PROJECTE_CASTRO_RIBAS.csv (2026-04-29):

Reference | Qty | Value | DNP | Exclude from BOM | Exclude from Board | Footprint | Datasheet
C1,C2,C3,C4,C5,C6,C8,C9 | 8 | 100n |  |  |  | Capacitor_SMD:C_0805_2012Metric | ~
C7 | 1 | 10u |  |  |  | Capacitor_SMD:C_0805_2012Metric | ~
C10,C11 | 2 | 22p |  |  |  | Capacitor_SMD:C_0805_2012Metric | ~
C20 | 1 | 33p |  |  |  | Capacitor_SMD:C_0805_2012Metric | ~
Cin_DCDC1 | 1 | 680uF |  |  |  | Capacitor_THT:C_Radial_D10.0mm_H12.5mm_P5.00mm | ~
Cin_reg1 | 1 | 10uF |  |  |  | Capacitor_SMD:C_0805_2012Metric
Connector_Bomba1,Connector_Tancament1,J4 | 3 | Conn_01x02_Pin |  |  |  | Connector_PinHeader_2.54mm:PinHeader_1x02_P2.54mm_Vertical | ~
Cout_DCDC1 | 1 | 220uF |  |  |  | Capacitor_THT:C_Radial_D10.0mm_H12.5mm_P5.00mm | ~
Cout_reg1 | 1 | 100uF |  |  |  | Capacitor_THT:CP_Radial_D5.0mm_P2.50mm | ~
D_Proteccio1 | 1 | D |  |  |  | Diode_SMD:D_SOD-123 | http://www.mccsemi.com/up_pdf/MBR0520~MBR0580(SOD123).pdf
D_proteccio_bomba1,D_proteccio_bomba2 | 2 | 1N4007 |  |  |  | Diode_THT:D_DO-41_SOD81_P10.16mm_Horizontal | http://www.vishay.com/docs/88503/1n4001.pdf
D_schottky_DCDC1 | 1 | 1N5824 |  |  |  | Diode_SMD:D_SMA | ~
D_Zener_Proteccio1 | 1 | 14Vz |  |  |  | Diode_SMD:D_SOD-123 | ~
FB1 | 1 | FerriteBead |  |  |  | Inductor_SMD:L_1812_4532Metric | ~
J1,J2 | 2 | DE9_Pins |  |  |  | Connector_Dsub:DSUB-9_Pins_Horizontal_P2.77x2.54mm_EdgePinOffset9.40mm | ~
J3 | 1 | Conn_01x05 |  |  |  | Connector_PinHeader_2.54mm:PinHeader_1x05_P2.54mm_Vertical | ~
K1,K2 | 2 | Fujitsu_FTR-LYAA005x |  |  |  | Relay_THT:Relay_SPST-NO_Fujitsu_FTR-LYAA005x_FormA_Vertical | https://www.fujitsu.com/sg/imagesgig5/ftr-ly.pdf
L1 | 1 | 18u |  |  |  | Inductor_SMD:L_0805_2012Metric | ~
L_DCDC1 | 1 | 33uH |  |  |  | Inductor_SMD:L_Bourns_SRP7028A_7.3x6.6mm | ~
MOSFET_controlbomba1,MOSFET_controltancament1 | 2 | IRLIZ44N |  |  |  | Package_TO_SOT_THT:TO-220F-3_Vertical | http://www.irf.com/product-info/datasheets/data/irliz44n.pdf
R1,R2,R6,R7,R40,R41 | 6 | 10k |  |  | Excluded from board | Resistor_SMD:R_0805_2012Metric | ~
R3,R4 | 2 | 4.7k |  |  |  | Resistor_SMD:R_0805_2012Metric | ~
R8,R9 | 2 | 220 |  |  |  | Resistor_SMD:R_0805_2012Metric | ~
RF_conn1 | 1 | Conn_01x04_Pin |  |  |  | Connector_PinSocket_2.54mm:PinSocket_1x04_P2.54mm_Vertical | ~
R_CAN_H_L1 | 1 | 120 |  |  |  | Resistor_SMD:R_0805_2012Metric | ~
SW3 | 1 | SW_Push_Dual |  |  |  | Button_Switch_SMD:SW_DIP_SPSTx02_Slide_6.7x6.64mm_W6.73mm_P2.54mm_LowProfile_JPin | ~
SW4,SW5 | 2 | SW_Push |  |  |  | Button_Switch_SMD:SW_DIP_SPSTx01_Slide_Copal_CHS-01B_W7.62mm_P1.27mm | ~
TP1 | 1 | Tp_3.3V |  |  |  | TestPoint:TestPoint_Keystone_5015_Micro_Mini | ~
TP2 | 1 | Tp_5V |  |  |  | TestPoint:TestPoint_Keystone_5015_Micro_Mini | ~
TP3 | 1 | Tp_12V |  |  |  | TestPoint:TestPoint_Keystone_5015_Micro_Mini | ~
TP4 | 1 | Tp_Osc_IN |  |  |  | TestPoint:TestPoint_Keystone_5015_Micro_Mini | ~
TP6 | 1 | Tp_GND |  |  |  | TestPoint:TestPoint_Keystone_5015_Micro_Mini | ~
TP7 | 1 | Tp_GNDPWR |  |  |  | TestPoint:TestPoint_Keystone_5015_Micro_Mini | ~
TP8 | 1 | Tp_12V_Bomba |  |  |  | TestPoint:TestPoint_Keystone_5015_Micro_Mini | ~
TP9 | 1 | Tp_12V_Tancament |  |  |  | TestPoint:TestPoint_Keystone_5015_Micro_Mini | ~
U1 | 1 | LM2596S-12 |  |  |  | Package_TO_SOT_SMD:TO-263-5_TabPin3 | http://www.ti.com/lit/ds/symlink/lm2596.pdf
U2 | 1 | LM1117DT-3.3 |  |  |  | Package_TO_SOT_SMD:TO-252-3_TabPin2 | http://www.ti.com/lit/ds/symlink/lm1117.pdf
U3 | 1 | SN65HVD230 |  |  |  | Package_SO:SOIC-8_3.9x4.9mm_P1.27mm | http://www.ti.com/lit/ds/symlink/sn65hvd230.pdf
U4 | 1 | MAX3232 |  |  |  | Package_SO:SOIC-16_3.9x9.9mm_P1.27mm | https://datasheets.maximintegrated.com/en/ds/MAX3222-MAX3241.pdf
U6 | 1 | FDC2214 |  |  |  | Package_DFN_QFN:MPS_QFN-16_3x3mm_P0.5mm
U20 | 1 | PIC24HJ128GP502 |  |  |  | Package_SO:SOIC-28W_7.5x17.9mm_P1.27mm
Y1 | 1 | Crystal |  |  |  | Crystal:Crystal_SMD_5032-2Pin_5.0x3.2mm | ~

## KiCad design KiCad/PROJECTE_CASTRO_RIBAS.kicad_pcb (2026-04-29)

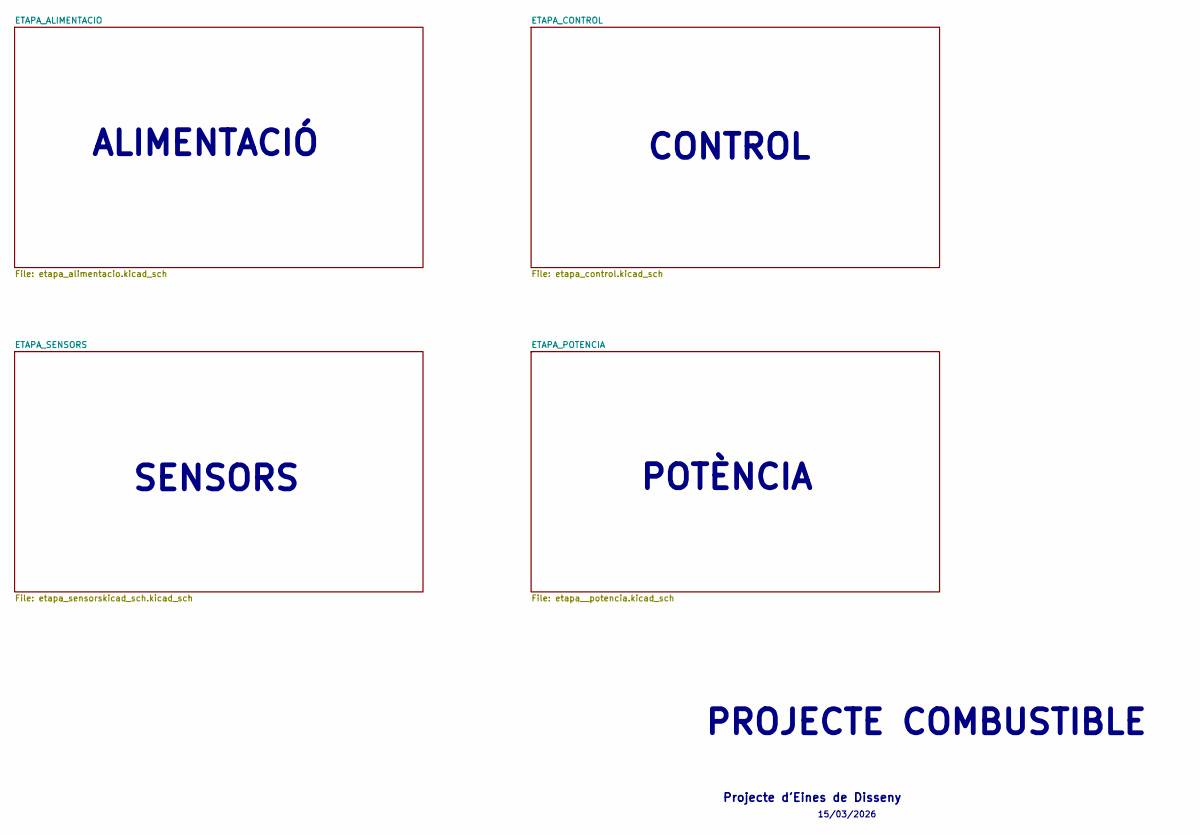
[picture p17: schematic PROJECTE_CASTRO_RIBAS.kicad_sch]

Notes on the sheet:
Projecte d'Eines de Disseny
PROJECTE COMBUSTIBLE
SENSORS
ALIMENTACIÓ
CONTROL
POTÈNCIA
15/03/2026

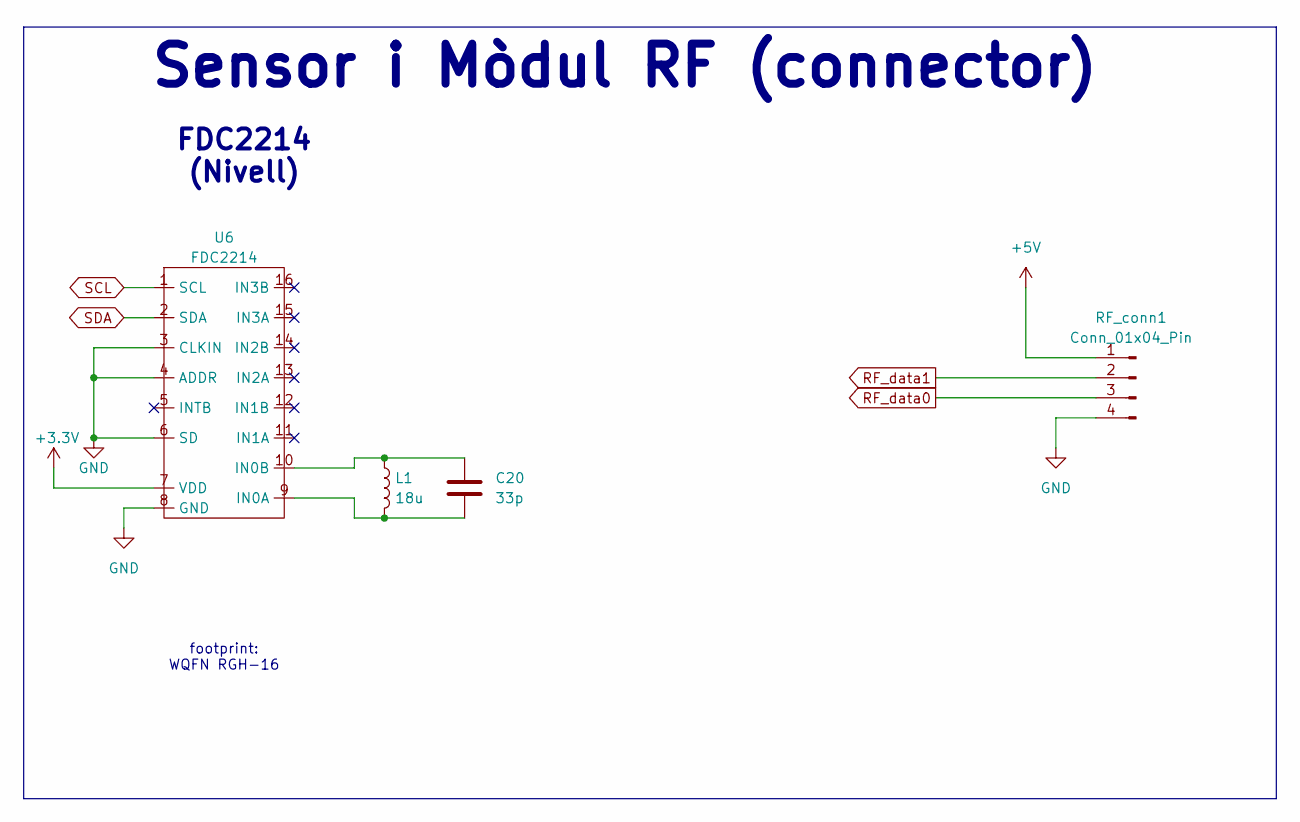
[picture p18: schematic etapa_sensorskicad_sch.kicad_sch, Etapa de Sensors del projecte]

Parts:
C20: 33p; C_0805_2012Metric
L1: 18u; L_0805_2012Metric
RF_conn1: Conn_01x04_Pin; PinSocket_1x04_P2.54mm_Vertical
U6: FDC2214; MPS_QFN-16_3x3mm_P0.5mm

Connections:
+3.3V: U6.7 (VDD); also elsewhere on the board
+5V: RF_conn1.1; also elsewhere on the board
GND: RF_conn1.4, U6.3 (CLKIN), U6.4 (ADDR), U6.6 (SD), U6.8 (GND); also elsewhere on the board
unnamed: C20.2, L1.2, U6.9 (IN0A)
unnamed: C20.1, L1.1, U6.10 (IN0B)
RF_data0: RF_conn1.3; also elsewhere on the board
RF_data1: RF_conn1.2; also elsewhere on the board
SCL: U6.1 (SCL); also elsewhere on the board
SDA: U6.2 (SDA); also elsewhere on the board

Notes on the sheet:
Sensor i Mòdul RF (connector)
FDC2214 (Nivell)
footprint: WQFN RGH-16

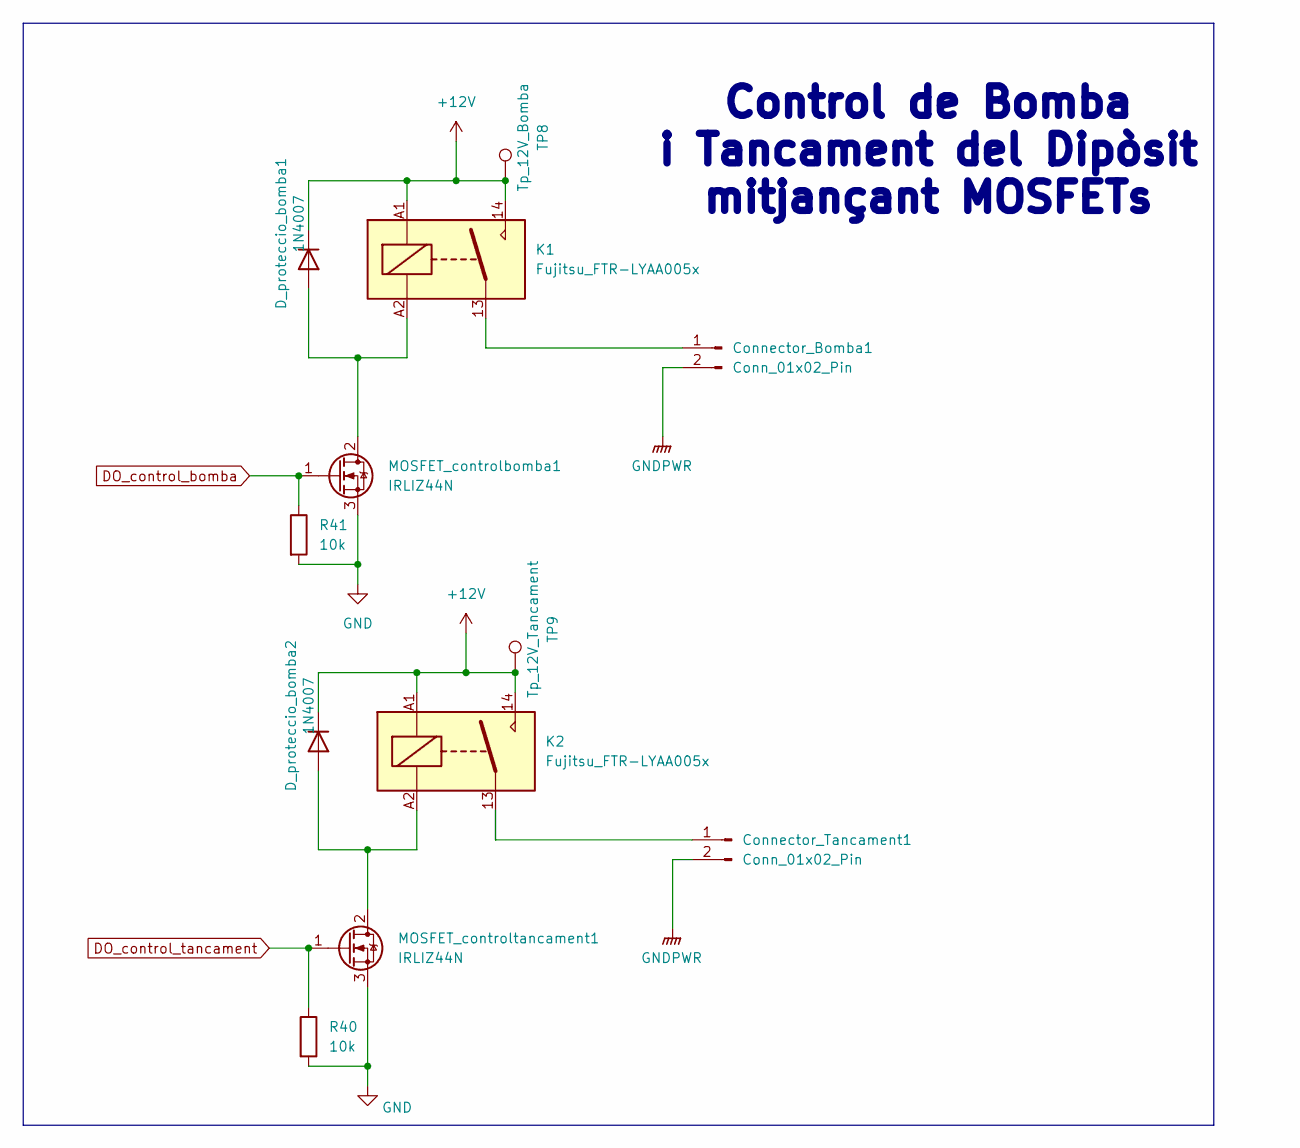
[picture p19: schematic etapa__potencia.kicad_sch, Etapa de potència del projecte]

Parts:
Connector_Bomba1: Conn_01x02_Pin; PinHeader_1x02_P2.54mm_Vertical
Connector_Tancament1: Conn_01x02_Pin; PinHeader_1x02_P2.54mm_Vertical
D_proteccio_bomba1, D_proteccio_bomba2: 1N4007; D_DO-41_SOD81_P10.16mm_Horizontal
K1, K2: Fujitsu_FTR-LYAA005x; Relay_SPST-NO_Fujitsu_FTR-LYAA005x_FormA_Vertical
MOSFET_controlbomba1: IRLIZ44N; TO-220F-3_Vertical
MOSFET_controltancament1: IRLIZ44N; TO-220F-3_Vertical
R40, R41: 10k; R_0805_2012Metric
TP8: Tp_12V_Bomba; TestPoint_Keystone_5015_Micro_Mini
TP9: Tp_12V_Tancament; TestPoint_Keystone_5015_Micro_Mini

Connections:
+12V: D_proteccio_bomba1.1 (K), D_proteccio_bomba2.1 (K), K1.14, K1.A1, K2.14, K2.A1, TP8.1, TP9.1; also elsewhere on the board
DO_control_bomba: MOSFET_controlbomba1.1 (G), R41.1; also elsewhere on the board
DO_control_tancament: MOSFET_controltancament1.1 (G), R40.1; also elsewhere on the board
GND: MOSFET_controlbomba1.3 (S), MOSFET_controltancament1.3 (S), R40.2, R41.2; also elsewhere on the board
GNDPWR: Connector_Bomba1.2, Connector_Tancament1.2; also elsewhere on the board
unnamed: Connector_Bomba1.1, K1.13
unnamed: Connector_Tancament1.1, K2.13
unnamed: D_proteccio_bomba1.2 (A), K1.A2, MOSFET_controlbomba1.2 (D)
unnamed: D_proteccio_bomba2.2 (A), K2.A2, MOSFET_controltancament1.2 (D)

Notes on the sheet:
Control de Bomba i Tancament del Dipòsit mitjançant MOSFETs

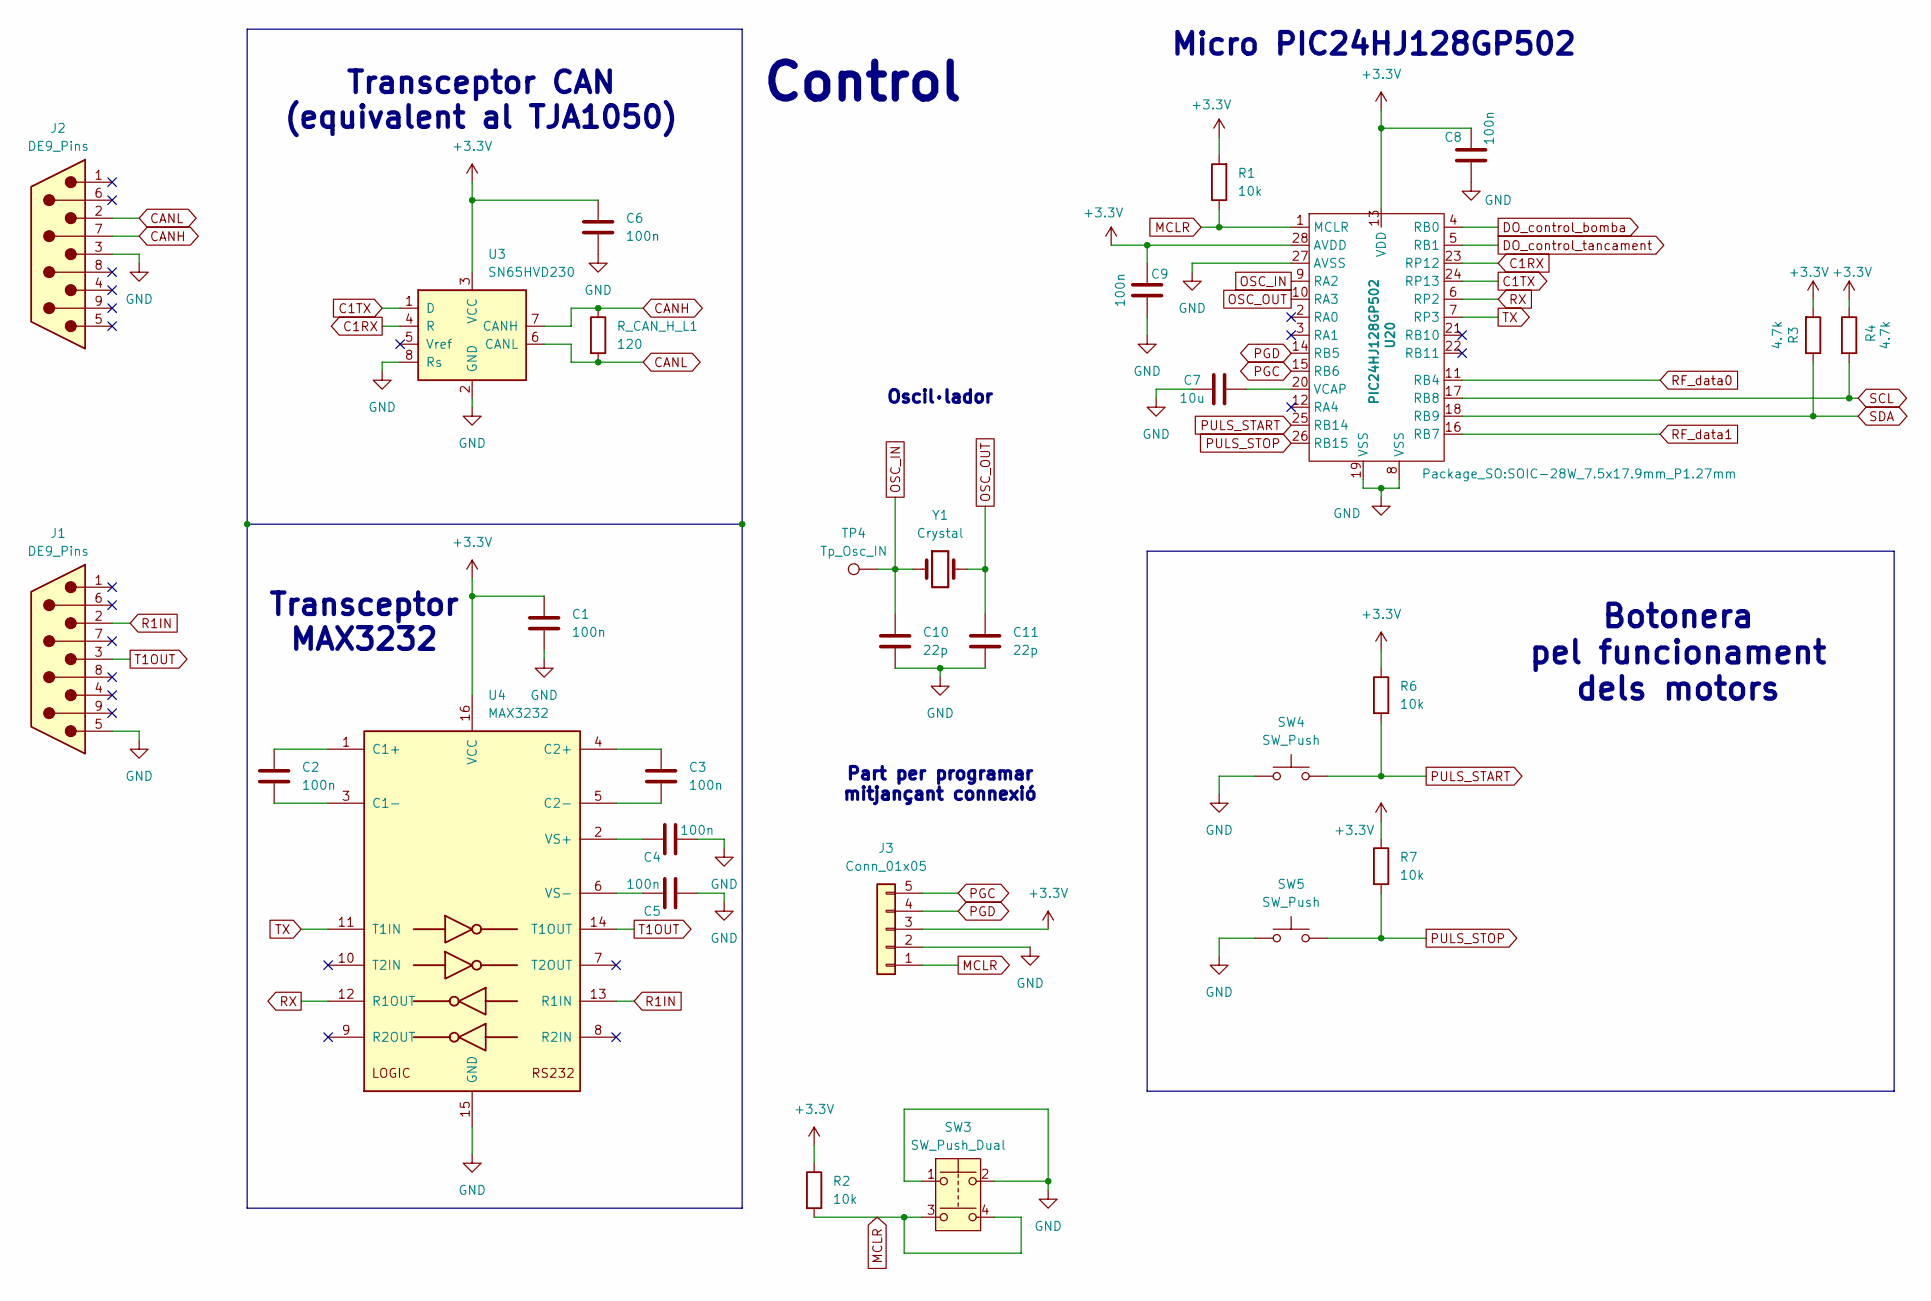
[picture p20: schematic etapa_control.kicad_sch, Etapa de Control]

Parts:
C1, C2, C3, C4, C5, C6, C8, C9: 100n; C_0805_2012Metric
C7: 10u; C_0805_2012Metric
C10, C11: 22p; C_0805_2012Metric
J1, J2: DE9_Pins; DSUB-9_Pins_Horizontal_P2.77x2.54mm_EdgePinOffset9.40mm
J3: Conn_01x05; PinHeader_1x05_P2.54mm_Vertical
R1, R2, R6, R7: 10k; R_0805_2012Metric
R3, R4: 4.7k; R_0805_2012Metric
R_CAN_H_L1: 120; R_0805_2012Metric
SW3: SW_Push_Dual; SW_DIP_SPSTx02_Slide_6.7x6.64mm_W6.73mm_P2.54mm_LowProfile_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
SW4, SW5: SW_Push; SW_DIP_SPSTx01_Slide_Copal_CHS-01B_W7.62mm_P1.27mm
TP4: Tp_Osc_IN; TestPoint_Keystone_5015_Micro_Mini
U3: SN65HVD230; SOIC-8_3.9x4.9mm_P1.27mm
U4: MAX3232; SOIC-16_3.9x9.9mm_P1.27mm
U20: PIC24HJ128GP502; SOIC-28W_7.5x17.9mm_P1.27mm
Y1: Crystal; Crystal_SMD_5032-2Pin_5.0x3.2mm

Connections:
+3.3V: C1.2, C6.2, C8.1, C9.1, J3.3, R1.2, R2.1, R3.2, R4.1, R6.1, R7.1, U3.3 (VCC), U4.16 (VCC), U20.13 (VDD), U20.28 (AVDD); also elsewhere on the board
C1RX: U3.4 (R), U20.23 (RP12)
C1TX: U3.1 (D), U20.24 (RP13)
CANH: J2.7, R_CAN_H_L1.1, U3.7 (CANH)
CANL: J2.2, R_CAN_H_L1.2, U3.6 (CANL)
DO_control_bomba: U20.4 (RB0); also elsewhere on the board
DO_control_tancament: U20.5 (RB1); also elsewhere on the board
GND: C1.1, C4.2, C5.2, C6.1, C7.2, C8.2, C9.2, C10.2, C11.2, J1.5, J2.3, J3.2, SW3.1, SW3.2, SW4.1, SW5.1, U3.2 (GND), U3.8 (Rs), U4.15 (GND), U20.8 (VSS), U20.19 (VSS), U20.27 (AVSS); also elsewhere on the board
MCLR: J3.1, R1.1, R2.2, SW3.3, SW3.4, U20.1 (MCLR)
unnamed: C2.1, U4.1 (C1+)
unnamed: C2.2, U4.3 (C1-)
unnamed: C3.1, U4.4 (C2+)
unnamed: C3.2, U4.5 (C2-)
unnamed: C4.1, U4.2 (VS+)
unnamed: C5.1, U4.6 (VS-)
unnamed: C7.1, U20.20 (VCAP)
OSC_IN: C10.1, TP4.1, U20.9 (RA2), Y1.1
OSC_OUT: C11.1, U20.10 (RA3), Y1.2
PGC: J3.5, U20.15 (RB6)
PGD: J3.4, U20.14 (RB5)
PULS_START: R6.2, SW4.2, U20.25 (RB14)
PULS_STOP: R7.2, SW5.2, U20.26 (RB15)
R1IN: J1.2, U4.13 (R1IN)
RF_data0: U20.11 (RB4); also elsewhere on the board
RF_data1: U20.16 (RB7); also elsewhere on the board
RX: U4.12 (R1OUT), U20.6 (RP2)
SCL: R4.2, U20.17 (RB8); also elsewhere on the board
SDA: R3.1, U20.18 (RB9); also elsewhere on the board
T1OUT: J1.3, U4.14 (T1OUT)
TX: U4.11 (T1IN), U20.7 (RP3)

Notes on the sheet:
Control
Transceptor CAN (equivalent al TJA1050)
Micro PIC24HJ128GP502
Transceptor MAX3232
Oscil·lador
Botonera pel funcionament dels motors
Part per programar mitjançant connexió

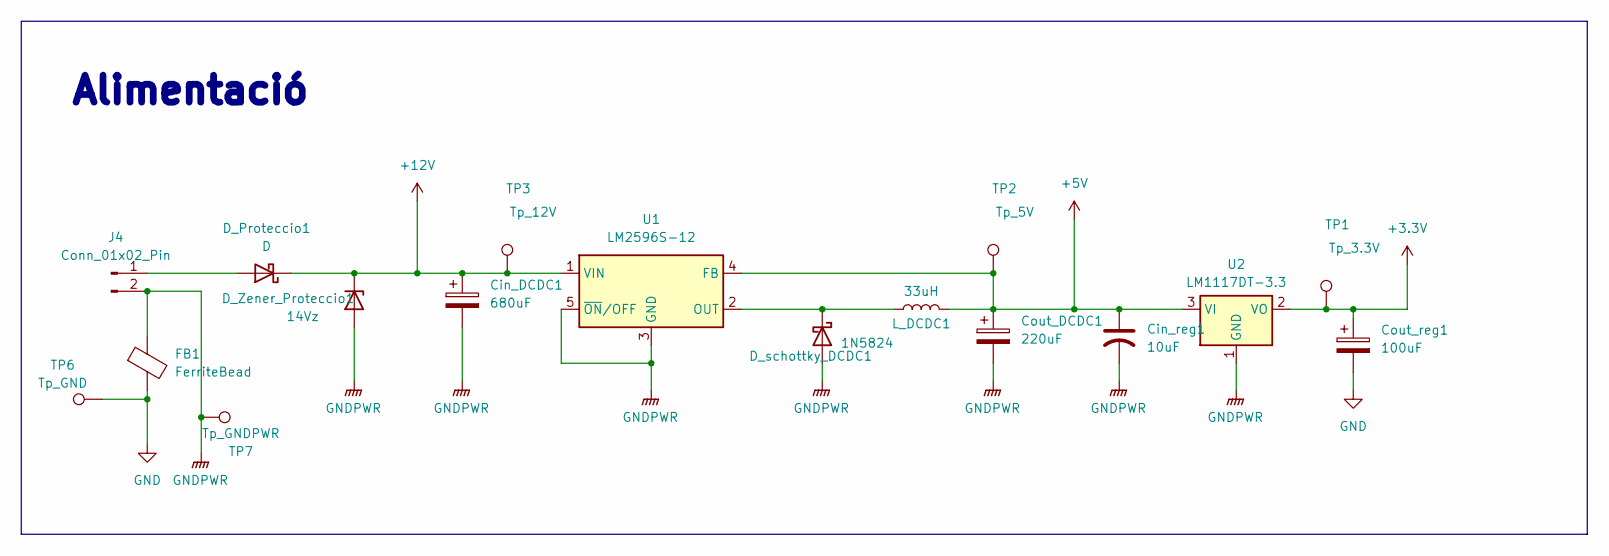
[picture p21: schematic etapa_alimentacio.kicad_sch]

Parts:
Cin_DCDC1: 680uF; C_Radial_D10.0mm_H12.5mm_P5.00mm
Cin_reg1: 10uF; C_0805_2012Metric
Cout_DCDC1: 220uF; C_Radial_D10.0mm_H12.5mm_P5.00mm
Cout_reg1: 100uF; CP_Radial_D5.0mm_P2.50mm
D_Proteccio1: D; D_SOD-123
D_Zener_Proteccio1: 14Vz; D_SOD-123
D_schottky_DCDC1: 1N5824; D_SMA
FB1: FerriteBead; L_1812_4532Metric
J4: Conn_01x02_Pin; PinHeader_1x02_P2.54mm_Vertical
L_DCDC1: 33uH; L_Bourns_SRP7028A_7.3x6.6mm
TP1: Tp_3.3V; TestPoint_Keystone_5015_Micro_Mini
TP2: Tp_5V; TestPoint_Keystone_5015_Micro_Mini
TP3: Tp_12V; TestPoint_Keystone_5015_Micro_Mini
TP6: Tp_GND; TestPoint_Keystone_5015_Micro_Mini
TP7: Tp_GNDPWR; TestPoint_Keystone_5015_Micro_Mini
U1: LM2596S-12; TO-263-5_TabPin3
U2: LM1117DT-3.3; TO-252-3_TabPin2

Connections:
+3.3V: Cout_reg1.1, TP1.1, U2.2 (VO); also elsewhere on the board
+5V: Cin_reg1.1, Cout_DCDC1.1, L_DCDC1.2, TP2.1, U1.4 (FB), U2.3 (VI); also elsewhere on the board
+12V: Cin_DCDC1.1, D_Proteccio1.1 (K), D_Zener_Proteccio1.1 (K), TP3.1, U1.1 (VIN); also elsewhere on the board
GND: Cout_reg1.2, FB1.2, TP6.1; also elsewhere on the board
GNDPWR: Cin_DCDC1.2, Cin_reg1.2, Cout_DCDC1.2, D_Zener_Proteccio1.2 (A), D_schottky_DCDC1.2 (A), FB1.1, J4.2, TP7.1, U1.3 (GND), U1.5 (~ON/OFF), U2.1 (GND); also elsewhere on the board
unnamed: D_Proteccio1.2 (A), J4.1
unnamed: D_schottky_DCDC1.1 (K), L_DCDC1.1, U1.2 (OUT)

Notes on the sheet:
Alimentació

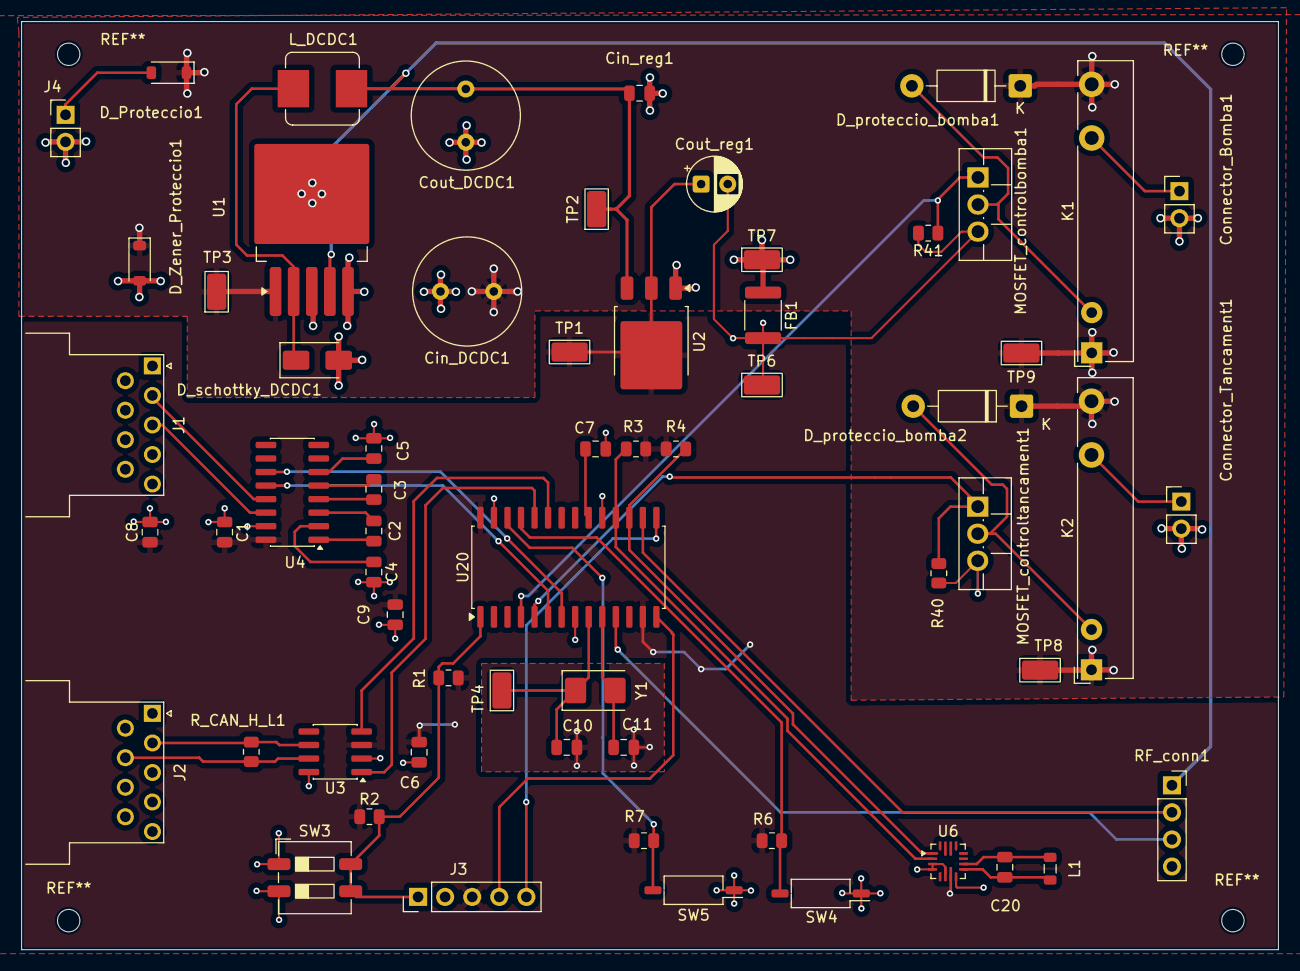
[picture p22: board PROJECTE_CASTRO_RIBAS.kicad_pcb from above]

Board: 2 copper layers, 117.9 x 87.1 mm, 62 parts (0 on the bottom side), 41 nets.

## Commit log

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2026-03-15 Canvis al diagrama de blocs, i subesquemes al kicad
    [etapa1potencia.kicad_sch, etapa2nometapa.kicad_sch, etapa3sensorsicontrol.kicad_sch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]
2026-03-15 Canvi nos etapes de l'esquematic
    [etapa2control.kicad_sch, etapa3sensors.kicad_sch, etapa4interaccio_comunicacio.kicad_sch]
2026-03-16 Canvis del probelam de l'esquematic
    [projecte_eines.kicad_sch]
2026-03-16 Borrada la carpeta del kicad per la liada del fucking edgar
    [etapa1potencia.kicad_sch, etapa2control.kicad_sch, etapa2nometapa.kicad_sch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]
2026-03-16 Tot Kicad Arreglat i Diagrama de blocs millorat (final?) fuckyouedgar
    [PROJECTE_CASTRO_RIBAS.kicad_pcb, PROJECTE_CASTRO_RIBAS.kicad_sch, etapa_4.kicad_sch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]
2026-03-16 Afegit el DCDC amb els seus 4 components externs
    [etapa_4.kicad_sch, etapa_control.kicad_sch, etapa_potencia.kicad_sch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]
2026-03-16 TOTS ELS NOMS DE LES ETAPES JA POSATS
    [PROJECTE_CASTRO_RIBAS.kicad_sch]
2026-03-17 Versió 1 de l'etapa de control quasi acabada (falta la part del micro)
    [etapa_control.kicad_sch]
2026-03-17 He afegit els LEDs i els botons, faltaria connectar-los als pins del Micro
    [etapa_interaccio_i_comunicacio.kicad_sch]
2026-03-17 Guardem completament la interacció i canvis de control
    [PROJECTE_CASTRO_RIBAS.kicad_sch, etapa_control.kicad_sch]
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2026-03-17 Sensors a la seva etapa (genèrics), falta el Micro amb els seus pins
    [etapa_sensorskicad_sch.kicad_sch]
2026-03-17 Afegeixo el simbol del Micro a l'etapa de control
    [control_v2.kicad_sch]
2026-03-17 Etapa de potencia acabada (potser s'han de cambiar els noms de les etiquetes pero tot lo altre OK)
    [etapa_potencia.kicad_sch]
2026-03-17 Posat els MOSFETS per el control, i els connectors per connectar la bomba i el tancament
    [etapa_sensorskicad_sch.kicad_sch]
2026-03-18 He afegit les etiquetes als pins RBO i RB1 per connectar a les sortides digitals que van als MOSFETS de control
    [control_v2.kicad_sch, etapa_interaccio_i_comunicacio.kicad_sch]
2026-03-18 Etapa Sensors modificada visualment, i global nets per control de bomba i tancament ja estan tirats edgar creo que te quiero
    [etapa_sensorskicad_sch.kicad_sch]
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2026-03-18 S'han afegit dos pins més, que venen de l'etapa de sensors. Amb això, crec que etapa de control i etapa de sensors connectat al micro
    [control_v2.kicad_sch]
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2026-03-19 Carpeta de simulacions creada i esquemàtics del MAIN borrats
    [control_v2.kicad_sch, etapa_interaccio_i_comunicacio.kicad_sch]
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2026-03-19 Hem afegit el simbol del sensor de nivell
    [etapa_sensorskicad_sch.kicad_sch]
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2026-03-22 Relé posat per protegir el MOSFET i el micro
    [etapa_sensorskicad_sch.kicad_sch]
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2026-03-24 Afegim les conexions al primer simbol que vam crear i modifiquem les definicions dels pins (SCL/SDA en bidireccional)
    [etapa_sensorskicad_sch.kicad_sch]
2026-03-24 Hem afegit el crystal, hem assignat els valors que faltaven en aquesta etapa, em afegit els pins que faltaven, com una petit part de programació (el connector) per si l'usuari vol programar alguna co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
    [control_v2.kicad_sch]
2026-03-25 Simbol del sensor de pressió creat, amb el seu possible footprint (?). A més, connexions necessàries fetes i eliminació dels connector que hi havien
    [etapa_sensorskicad_sch.kicad_sch]
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2026-03-25 Alguns errors resolts, falten errors com canviar noms de unitats ''duplicats'', es fará en cas de que ja estigui tot bastant correcte
    [control_v2.kicad_sch, etapa_interaccio_i_comunicacio.kicad_sch, etapa_potencia.kicad_sch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]
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2026-03-26 Revert "M'he perdut uwu"
    This reverts commit 75ca1c4609618d7f473fb36f5350017eae0bb0fd, reversing
    changes made to 4a0edfe9f91ce7fcb83a65e8ac9f1b9b9c694731.
    [control_v2.kicad_sch]
2026-03-26 GNDs, VCCs col.locats correctament, pull-ups, etc ben connectats
    [control_v2.kicad_sch, etapa_interaccio_i_comunicacio.kicad_sch, etapa_potencia.kicad_sch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]
2026-03-29 Algunes pejades afegides a l'etapa de potència i de control (només els components importants)
    [control_v2.kicad_sch, etapa_potencia.kicad_sch]
2026-03-29 Afegides TOTES les petjades importants MENYS SENSOR de PRESSIO
    [control_v2.kicad_sch, etapa_interaccio_i_comunicacio.kicad_sch, etapa_sensorskicad_sch.kicad_sch]
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2026-03-30 Més FXTH87, alguna petjada més, i molts dubtes
    [control_v2.kicad_sch, etapa_potencia.kicad_sch, etapa_sensorskicad_sch.kicad_sch]
2026-04-01 Afegim un polsador per la part del RESET del Micro
    [control_v2.kicad_sch]
2026-04-01 Posem una part que estava en el subesquemàtic de sesnors al de potència (el control de la bomba i del dipòsit)
    [etapa_potencia.kicad_sch, etapa_sensorskicad_sch.kicad_sch]
2026-04-04 push ràpid, falta pull ups del sensor de pressio al micro
    [control_v2.kicad_sch, etapa_potencia.kicad_sch, etapa_sensorskicad_sch.kicad_sch]
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2026-04-04 Canvi de forma de dos pins --> ESQUEMÀTIC ACABAT
    [control_v2.kicad_sch]
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2026-04-08 Readme alguns proveïdors i foto del diagrama de blocs
    [PROJECTE_CASTRO_RIBAS.kicad_pcb]
2026-04-09 ALFRED DEGANOS SECOOOOS PLS DADDY ALFRED TE CAMELAMOS
    [PROJECTE_CASTRO_RIBAS.kicad_pcb, etapa__potencia.kicad_sch, etapa_alimentacio.kicad_sch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]
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2026-04-15 Routing de l'alimentació fet, s'ha afegit connector del mòdul RF i plànols millorats
    [PROJECTE_CASTRO_RIBAS.kicad_pcb, etapa_alimentacio.kicad_sch, etapa_control.kicad_sch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]
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2026-04-16 Petits canvis a les regles de disseny i ja no hi ha cap error (hi han avisos)
    [PROJECTE_CASTRO_RIBAS.kicad_pcb]
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2026-04-25 No he modificat res pero joquese li he donat a guardar i ara haig de fer un commit xd whatahellyburton
    [PROJECTE_CASTRO_RIBAS.kicad_pcb]
2026-04-25 No Silkscreen errors ni res per l'estil, a punt per treure els gerbers per pressupost pcb
    [PROJECTE_CASTRO_RIBAS.kicad_pcb, etapa__potencia.kicad_sch, etapa_control.kicad_sch]
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2026-04-28 Gerbers en zip i carpeta de pressupsost feta
    [PROJECTE_CASTRO_RIBAS-B_Cu.gbr, PROJECTE_CASTRO_RIBAS-B_Mask.gbr, PROJECTE_CASTRO_RIBAS-B_Paste.gbr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]
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2026-04-30 COMMIT FINAL OS AMAMOS A TODOS MEUS AMOREEEES (al final la prese ha surtit super be i tot i tenir una mica de nerbis estem super contents<3 ^.^ alfred tastimu)
    [BOM_PROJECTE_CASTRO_RIBAS.csv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]
